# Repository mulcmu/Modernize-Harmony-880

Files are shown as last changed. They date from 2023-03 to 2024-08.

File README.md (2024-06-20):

# Modernize Harmony 880
 Modernize a Logitech Harmony 880 universal remote

# Details

The Logitech Harmony 880 is a universal infrared remote intended to control the numerous parts of a home theater system with one remote. The Harmony remotes are programmable allowing sequences of IR commands to be sent to start an activity. So "Watch Blu-ray" could be configured to turn on TV, receiver, and blu-ray player player, and set TV and receiver to correct inputs. Convenient to keep from needing numerous remotes to start an activity. Programming is performed using Logitech internet based software to update the remote via a USB connection. In 2021, Logitech announced that they would discontinue Harmony Remote [manufacturing](https://support.logi.com/hc/en-us/community/posts/1500000658341). The release indicates support would still continue software support, who knows how long that will remain.

The 880 remote build is great quality. I'm not sure exactly when I got mine but it is upwards of 15 years of service with only some cosmetic wear to the buttons. It has a rechargeable battery, that charges in a storage cradle. Over the years the universality of the remote has diminished as more devices use RF remote protocols. To keep the 880 working after getting a Roku box, an ESP8266 needed to be setup to [translate IR remote](https://github.com/mulcmu/IRtoRokuBridge) signals to HTTP POST commands.

This project is undertaking an upgrade for the 880 universal remote to, update screen to TFT with better resolution, build in wifi connectivity, and provide an open source software solution for setup and programming.

Current PCB design has all existing remote features implemented, hardware and software testing in process.

# Project Logs

https://hackaday.io/project/185926-modernize-harmony-880

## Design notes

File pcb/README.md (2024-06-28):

# Alpha3 PCB

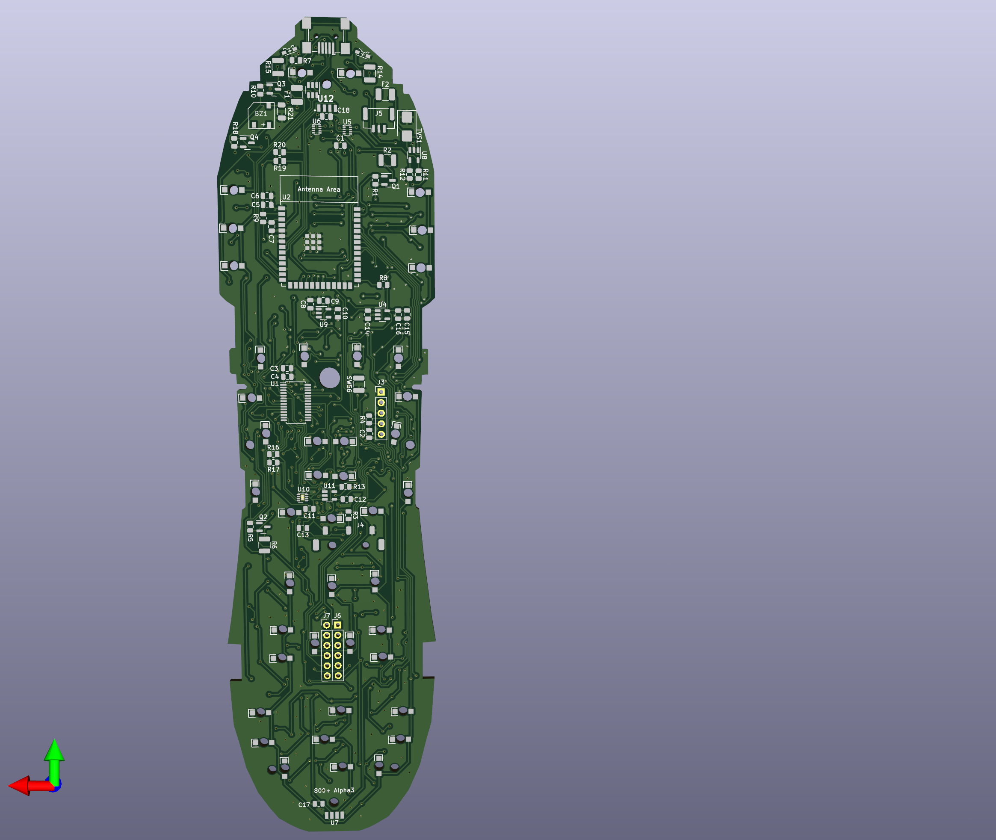
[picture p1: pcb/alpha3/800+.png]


Alpha3 PCB designed and ordered to test the peripheral operation.  Should be functionally complete if everything works.

There are some clearance issues with the bottom of remote case screw bosses interfering with parts on bottom of board.

# Alpha2 PCB

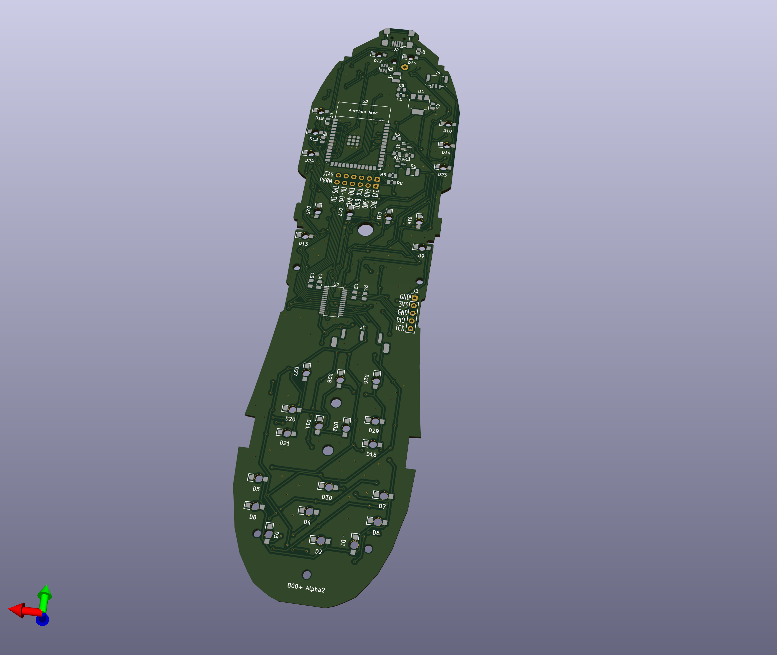
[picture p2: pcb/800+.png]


Updated the Kicad project for another alpha PCB.  Two layer PCB again but 0.8mm thick to fully test fitup with case.

* Fixed mosfet for the button led backlight
* Put an ESP32-S3 module on the board.
* USB wired up to the ESP32, 3.3V supply from the usb 5V.

# Alpha PCB

Kicad files for the alpha PCB.  Overall dimensions were okay.  The sides by the LCD might need trimmed down a smidge but there isn't much room for the button contacts.

Two layer PCB to keep cost down.  I ordered a 1.6mm thick but the stock board was 0.8mm so the case wouldn't snap shut properly.

##### Bare Screen

https://www.alibaba.com/product-detail/Lcd-Screen-Display-2-Inch-240x320_1600053711661.html

##### 4mm dome switches

https://www.aliexpress.us/item/2255799854582341

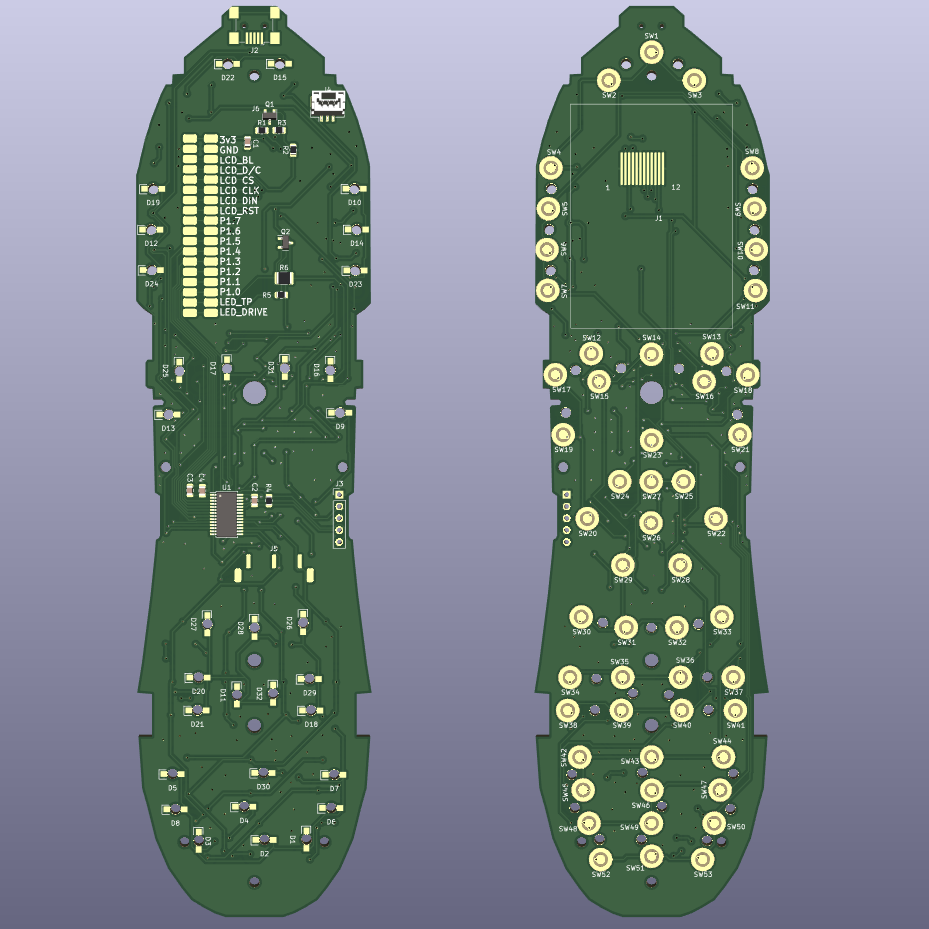
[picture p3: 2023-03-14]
pcb/alpha/back.png

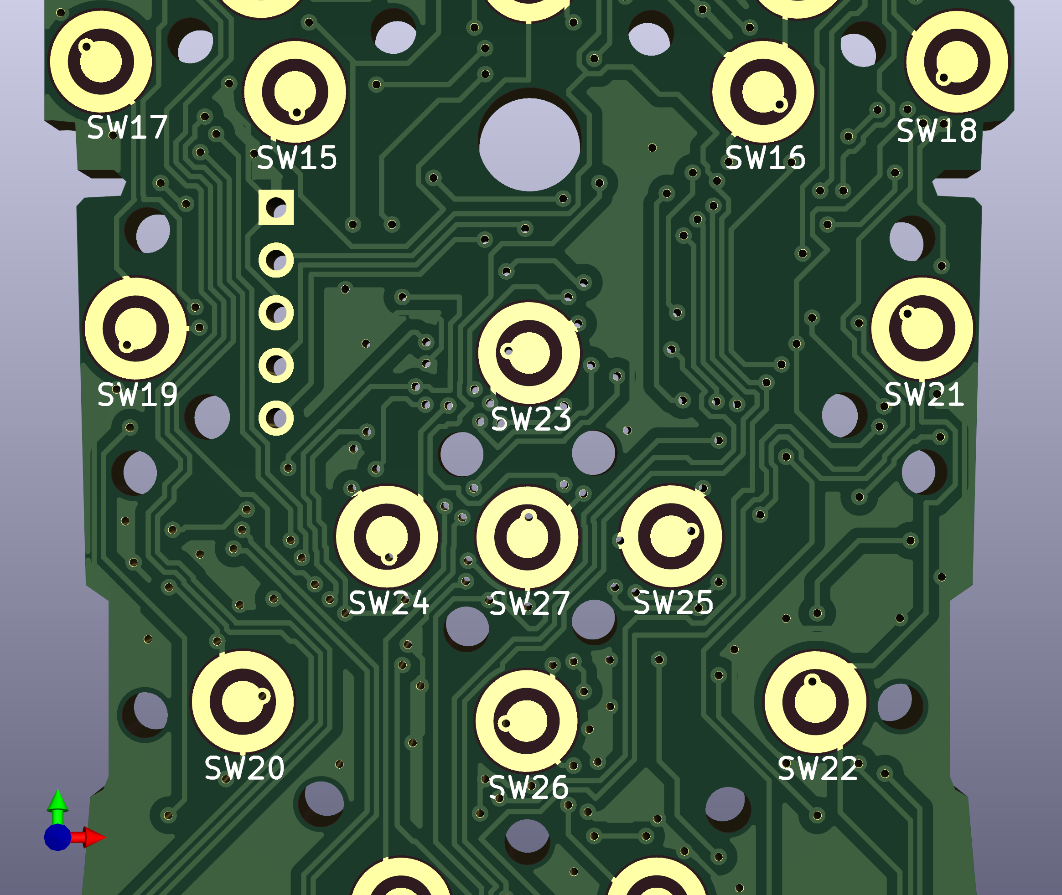
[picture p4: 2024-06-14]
pcb/alpha3/front.png

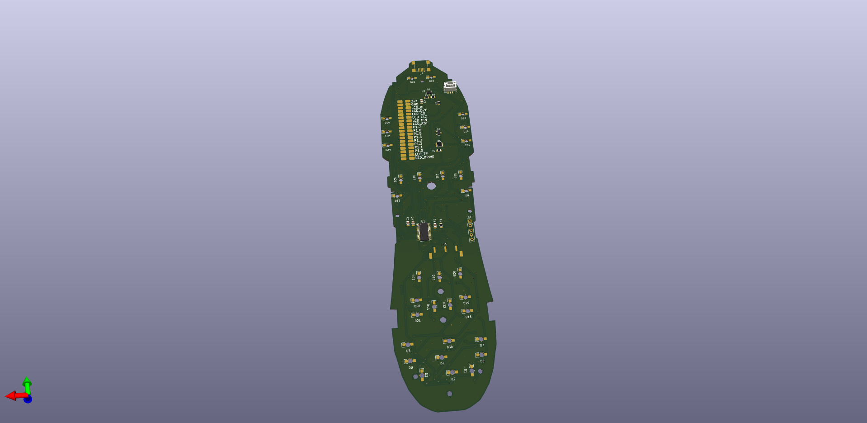
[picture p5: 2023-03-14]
pcb/alpha/iso1.png

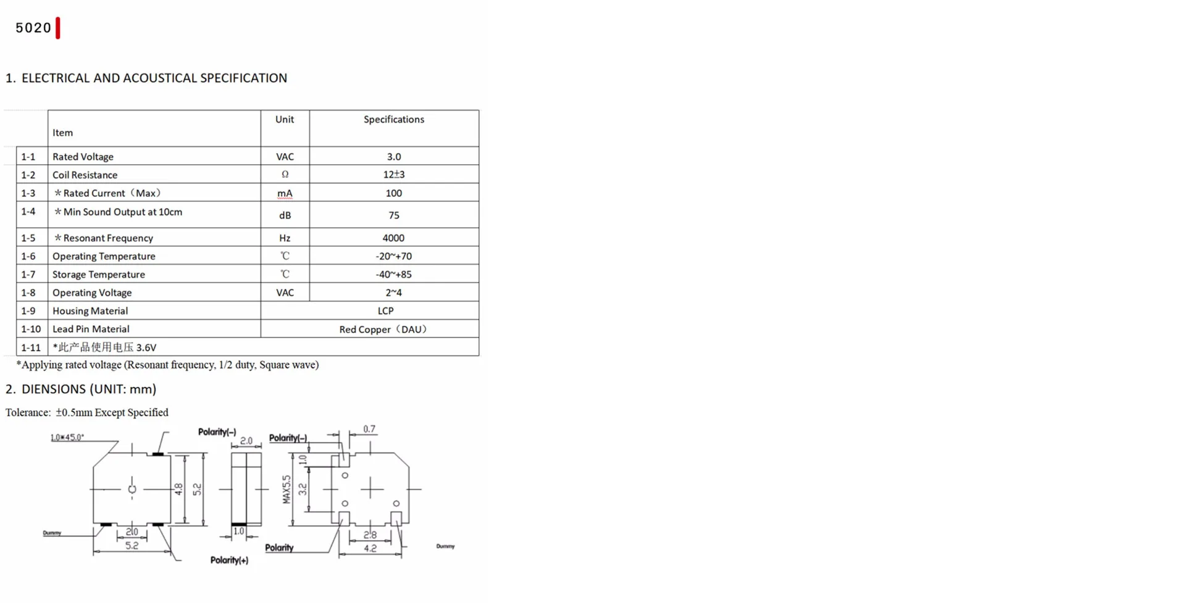
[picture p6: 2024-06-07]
pcb/buzzer.png

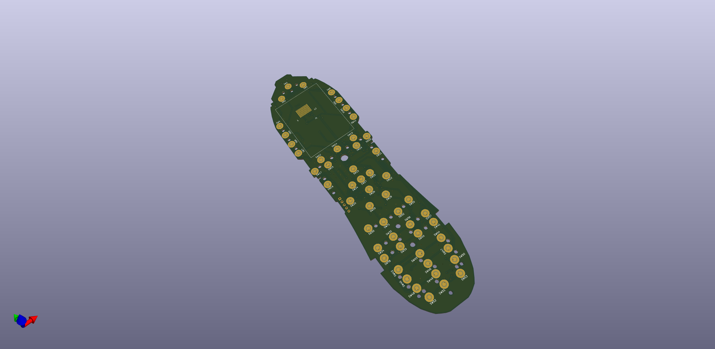
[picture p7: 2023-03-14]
pcb/alpha/iso2.png

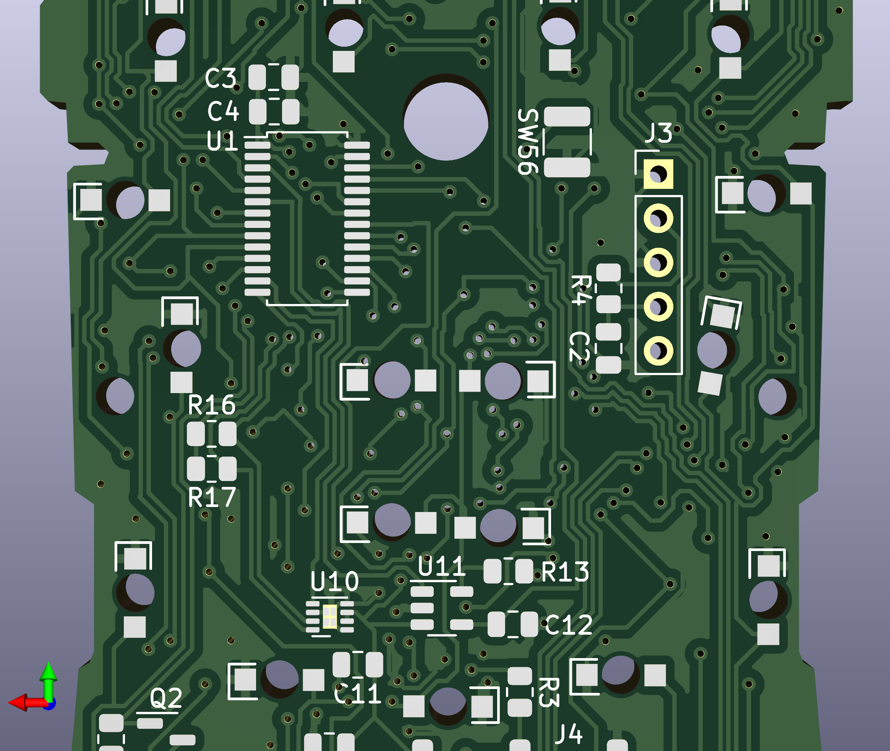
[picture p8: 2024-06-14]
pcb/alpha3/bottom.png

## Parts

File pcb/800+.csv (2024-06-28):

Source: | C:\Users\Ryan\Documents\GitHub\mulcmu\Modernize-Harmony-880\pcb\800+.kicad_sch
Date: | 6/23/2024 4:27:52 PM
Tool: | Eeschema 7.0.10
Generator: | C:\Program Files\KiCad\7.0\bin\scripting\plugins/bom_csv_grouped_by_value.py
Component Count: | 161
Collated Components:
Item | Qty | Reference(s) | Value | LibPart | Footprint | Datasheet | DNP | Imax | Iq | Manufacturer_Name | Manufacturer_Part_Number | Mouser Part Number | Mouser Price/Stock | PROD_ID | Tolerance | VMax | Voltage
1 | 1 | BZ1 | 5020 Passive | Device:Buzzer | 880+:5020passiveBuzzer | ~
2 | 2 | C1, C7 | 1u | Device:C | Capacitor_SMD:C_0805_2012Metric | ~
3 | 1 | C2 | 1.1nF | Device:C | Capacitor_SMD:C_0805_2012Metric | ~
4 | 3 | C3, C5, C6 | 10u | Device:C | Capacitor_SMD:C_0805_2012Metric | ~
5 | 1 | C4 | .1u | Device:C | Capacitor_SMD:C_0805_2012Metric | ~
6 | 2 | C8, C14 | 2.2uF | SparkFun-Capacitor:2.2uF_0402_10V_10% | SparkFun-Capacitor:C_0402_1005Metric | https://cdn.sparkfun.com/assets/8/a/4/a/5/Kemet_Capacitor_Datasheet.pdf |  |  |  |  |  |  |  | CAP-14232 | 10% |  | 10V
7 | 3 | C9, C11, C15 | 0.1uF | SparkFun-Capacitor:0.1uF_0402_6.3V_10% | SparkFun-Capacitor:C_0402_1005Metric | https://cdn.sparkfun.com/assets/8/a/4/a/5/Kemet_Capacitor_Datasheet.pdf |  |  |  |  |  |  |  | CAP-14993 | 10% |  | 6.3V
8 | 2 | C10, C16 | 1.0uF | SparkFun-Capacitor:1.0uF_0402_16V_10% | SparkFun-Capacitor:C_0402_1005Metric | https://cdn.sparkfun.com/assets/8/a/4/a/5/Kemet_Capacitor_Datasheet.pdf |  |  |  |  |  |  |  | CAP-14969 | 10% |  | 16V
9 | 1 | C12 | 4.7uF | SparkFun-Capacitor:4.7uF_0603_35V_20% | SparkFun-Capacitor:C_0603_1608Metric | https://cdn.sparkfun.com/assets/8/a/4/a/5/Kemet_Capacitor_Datasheet.pdf |  |  |  |  |  |  |  | CAP-14106 | 20% |  | 35V
10 | 1 | C13 | 4.7uF | SparkFun-Capacitor:4.7uF_0402_6.3V_10% | SparkFun-Capacitor:C_0402_1005Metric | https://cdn.sparkfun.com/assets/8/a/4/a/5/Kemet_Capacitor_Datasheet.pdf |  |  |  |  |  |  |  | CAP-14240 | 20% |  | 6.3V
11 | 32 | D1, D2, D3, D4, D5, D6, D7, D8, D9, D10, D11, D12, D13, D14, D15, D16, D17, D18, D19, D20, D21, D22, D23, D24, D25, D26, D27, D28, D29, D30, D31, D32 | LED | Device:LED | 880+:C265_reverse_mount_led_DRC | ~
12 | 2 | D33, D34 | LED | Device:LED | 880+:IR_led | ~
13 | 1 | D35 | P6SMB12CA | Device:D_TVS | Diode_SMD:D_SMB | ~
14 | 2 | F1, F2 | Polyfuse | Device:Polyfuse | Resistor_SMD:R_1210_3225Metric_Pad1.30x2.65mm_HandSolder | https://www.mouser.com/ProductDetail/Bourns/MF-MSMF030-2?qs=4Enggx7jqVwuh3vnyeU3lA%3D%3D
15 | 1 | H1 | Screw Recess | Mechanical:MountingHole | MountingHole:MountingHole_5mm | ~
16 | 2 | H4, H5 | Battery Alignment | Mechanical:MountingHole | MountingHole:MountingHole_2.1mm | ~
17 | 4 | H6, H7, H8, H9 | Case Screw | Mechanical:MountingHole | MountingHole:MountingHole_2.2mm_M2 | ~
18 | 1 | J1 | 2inch LCD | Connector_Generic:Conn_01x12 | 880+:2inch_LCD | ~
19 | 1 | J2 | USB_B_Micro | Connector:USB_B_Micro | Connector_USB:USB_Mini-B_Wuerth_65100516121_Horizontal | ~
20 | 1 | J3 | MSP_SBW | Connector_Generic:Conn_01x05 | Connector_PinHeader_2.54mm:PinHeader_1x05_P2.54mm_Vertical | ~
21 | 1 | J4 | Battery | Connector_Generic:Conn_01x03 | 880+:Battery_reuse | ~
22 | 1 | J5 | Cradle | Connector_Generic:Conn_01x03 | Connector_JST:JST_GH_BM03B-GHS-TBT_1x03-1MP_P1.25mm_Vertical | ~
23 | 1 | J6 | ESP_JTAG | Connector:Conn_01x06_Socket | Connector_PinHeader_2.54mm:PinHeader_1x06_P2.54mm_Vertical | ~
24 | 1 | J7 | ESP_PROG | Connector:Conn_01x06_Socket | Connector_PinHeader_2.54mm:PinHeader_1x06_P2.54mm_Vertical | ~
25 | 4 | Q1, Q2, Q3, Q4 | AO3401A | Transistor_FET:AO3401A | Package_TO_SOT_SMD:SOT-23 | http://www.aosmd.com/pdfs/datasheet/AO3401A.pdf
26 | 6 | R1, R5, R8, R9, R10, R18 | 10k | Device:R | Resistor_SMD:R_0805_2012Metric | ~
27 | 2 | R2, R6 | 10 | Device:R | Resistor_SMD:R_1210_3225Metric | ~
28 | 1 | R3 | R | Device:R | Resistor_SMD:R_0805_2012Metric | ~
29 | 1 | R4 | 47k | Device:R | Resistor_SMD:R_0805_2012Metric | ~
30 | 1 | R7 | 1M | Device:R | Resistor_SMD:R_0805_2012Metric | ~
31 | 2 | R11, R12 | R | Device:R |  | ~
32 | 1 | R13 | 2k | Device:R | Resistor_SMD:R_0805_2012Metric | ~
33 | 2 | R14, R15 | 22 | Device:R | Resistor_SMD:R_1210_3225Metric | ~
34 | 4 | R16, R17, R19, R20 | 4.7k | Device:R | Resistor_SMD:R_0805_2012Metric | ~
35 | 1 | R21 | 0 | Device:R | Resistor_SMD:R_1206_3216Metric | ~
36 | 1 | SW1 | Off | Switch:SW_Push | 880+:4mm Dome | ~
37 | 1 | SW2 | Activities | Switch:SW_Push | 880+:4mm Dome | ~
38 | 1 | SW3 | Help | Switch:SW_Push | 880+:4mm Dome | ~
39 | 1 | SW4 | L_LCD1 | Switch:SW_Push | 880+:4mm Dome | ~
40 | 1 | SW5 | L_LCD2 | Switch:SW_Push | 880+:4mm Dome | ~
41 | 1 | SW6 | L_LCD3 | Switch:SW_Push | 880+:4mm Dome | ~
42 | 1 | SW7 | L_LCD4 | Switch:SW_Push | 880+:4mm Dome | ~
43 | 1 | SW8 | R_LCD1 | Switch:SW_Push | 880+:4mm Dome | ~
44 | 1 | SW9 | R_LCD2 | Switch:SW_Push | 880+:4mm Dome | ~
45 | 1 | SW10 | R_LCD3 | Switch:SW_Push | 880+:4mm Dome | ~
46 | 1 | SW11 | R_LCD4 | Switch:SW_Push | 880+:4mm Dome | ~
47 | 1 | SW12 | LCD_LEFT | Switch:SW_Push | 880+:4mm Dome | ~
48 | 1 | SW13 | LCD_RIGHT | Switch:SW_Push | 880+:4mm Dome | ~
49 | 1 | SW14 | Glow | Switch:SW_Push | 880+:4mm Dome | ~
50 | 1 | SW15 | Device | Switch:SW_Push | 880+:4mm Dome | ~
51 | 1 | SW16 | Media | Switch:SW_Push | 880+:4mm Dome | ~
52 | 1 | SW17 | Mute | Switch:SW_Push | 880+:4mm Dome | ~
53 | 1 | SW18 | Prev | Switch:SW_Push | 880+:4mm Dome | ~
54 | 1 | SW19 | Vol+ | Switch:SW_Push | 880+:4mm Dome | ~
55 | 1 | SW20 | Vol- | Switch:SW_Push | 880+:4mm Dome | ~
56 | 1 | SW21 | Ch+ | Switch:SW_Push | 880+:4mm Dome | ~
57 | 1 | SW22 | Ch- | Switch:SW_Push | 880+:4mm Dome | ~
58 | 1 | SW23 | Dpad_Up | Switch:SW_Push | 880+:4mm Dome | ~
59 | 1 | SW24 | Dpad_Left | Switch:SW_Push | 880+:4mm Dome | ~
60 | 1 | SW25 | Dpad_Right | Switch:SW_Push | 880+:4mm Dome | ~
61 | 1 | SW26 | Dpad_Down | Switch:SW_Push | 880+:4mm Dome | ~
62 | 1 | SW27 | Dpad_OK | Switch:SW_Push | 880+:4mm Dome | ~
63 | 1 | SW28 | PgUp/Grn | Switch:SW_Push | 880+:4mm Dome | ~
64 | 1 | SW29 | PgDown/Yel | Switch:SW_Push | 880+:4mm Dome | ~
65 | 1 | SW30 | Menu | Switch:SW_Push | 880+:4mm Dome | ~
66 | 1 | SW31 | Exit | Switch:SW_Push | 880+:4mm Dome | ~
67 | 1 | SW32 | Guide | Switch:SW_Push | 880+:4mm Dome | ~
68 | 1 | SW33 | Info | Switch:SW_Push | 880+:4mm Dome | ~
69 | 1 | SW34 | Stop | Switch:SW_Push | 880+:4mm Dome | ~
70 | 1 | SW35 | Replay | Switch:SW_Push | 880+:4mm Dome | ~
71 | 1 | SW36 | Skip | Switch:SW_Push | 880+:4mm Dome | ~
72 | 1 | SW37 | Play | Switch:SW_Push | 880+:4mm Dome | ~
73 | 1 | SW38 | Rec | Switch:SW_Push | 880+:4mm Dome | ~
74 | 1 | SW39 | Rew | Switch:SW_Push | 880+:4mm Dome | ~
75 | 1 | SW40 | Fwd | Switch:SW_Push | 880+:4mm Dome | ~
76 | 1 | SW41 | Pause | Switch:SW_Push | 880+:4mm Dome | ~
77 | 1 | SW42 | KP_1 | Switch:SW_Push | 880+:4mm Dome | ~
78 | 1 | SW43 | KP_2 | Switch:SW_Push | 880+:4mm Dome | ~
79 | 1 | SW44 | KP_3 | Switch:SW_Push | 880+:4mm Dome | ~
80 | 1 | SW45 | KP_4 | Switch:SW_Push | 880+:4mm Dome | ~
81 | 1 | SW46 | KP_5 | Switch:SW_Push | 880+:4mm Dome | ~
82 | 1 | SW47 | KP_6 | Switch:SW_Push | 880+:4mm Dome | ~
83 | 1 | SW48 | KP_7 | Switch:SW_Push | 880+:4mm Dome | ~
84 | 1 | SW49 | KP_8 | Switch:SW_Push | 880+:4mm Dome | ~
85 | 1 | SW50 | KP_9 | Switch:SW_Push | 880+:4mm Dome | ~
86 | 1 | SW51 | KP_0 | Switch:SW_Push | 880+:4mm Dome | ~
87 | 1 | SW52 | KP_Clear | Switch:SW_Push | 880+:4mm Dome | ~
88 | 1 | SW53 | KP_Enter | Switch:SW_Push | 880+:4mm Dome | ~
89 | 1 | SW54 | Red | Switch:SW_Push | 880+:4mm Dome | ~
90 | 1 | SW55 | Blue | Switch:SW_Push | 880+:4mm Dome | ~
91 | 1 | SW56 | SW_RollingBall | 880+:SW_RollingBall | Resistor_SMD:R_1210_3225Metric | ~
92 | 1 | U1 | MSP430G2553IPW28 | MCU_Texas_MSP430:MSP430G2553IPW28 | Package_SO:TSSOP-28_4.4x9.7mm_P0.65mm | http://www.ti.com/lit/ds/symlink/msp430g2553.pdf
93 | 1 | U2 | ESP32-S3-WROOM-1U | PCM_Espressif:ESP32-S3-WROOM-1 | PCM_Espressif:ESP32-S3-WROOM-1 | https://www.espressif.com/sites/default/files/documentation/esp32-s3-wroom-1_wroom-1u_datasheet_en.pdf
94 | 1 | U3 | USBLC6-2 | Random_SRAM_Parts:USBLC6_Fixed | Package_TO_SOT_SMD:SOT-23-6
95 | 2 | U4, U9 | RT9080-3.3 | SparkFun-Regulator:RT9080-3.3 | SparkFun-Semiconductor-Standard:SOT23-5 | https://www.richtek.com/SaveDownload.aspx?specid=RT9080 |  | 600mA | 4µA |  |  |  |  | VREG-19034 |  | 6V
96 | 2 | U5, U6 | LM66200DRLR | 880+:LM66200DRLR | SOT-5X3_DRL_TEX | LM66200DRLR
97 | 1 | U7 | TSOP75340TT | 880+:TSOP75340TT | 880+:IR_input
98 | 1 | U8 | SPX3819M5-L | Regulator_Linear:SPX3819M5-L | Package_TO_SOT_SMD:SOT-23-5 | https://www.exar.com/content/document.ashx?id=22106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
99 | 1 | U10 | MAX17048 | SparkFun-IC-Power:MAX17048 | SparkFun-Semiconductor-Standard:DFN-8 | https://www.analog.com/media/en/technical-documentation/data-sheets/MAX17048-MAX17049.pdf |  |  |  |  |  |  |  | IC-12551
100 | 1 | U11 | MCP73831 | SparkFun-IC-Power:MCP73831 | SparkFun-Semiconductor-Standard:SOT23-5 | http://ww1.microchip.com/downloads/en/DeviceDoc/20001984g.pdf |  |  |  |  |  |  |  | IC-09995
101 | 1 | U12 | VEML7700-TR | 880+:VEML7700-TT | 880+:VEML7700 | https://www.arrow.com/en/products/veml7700-tt/vishay |  |  |  | Vishay | VEML7700-TT | 78-VEML7700-TT | https://www.mouser.co.uk/ProductDetail/Vishay-Semiconductors/VEML7700-TT?qs=BcfjnG7NVaXdL6DJFdWbdw%3D%3D

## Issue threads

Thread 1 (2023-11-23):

Status on PCB

mbake2, 2023-11-23:
What's the status on the PCB boards of the remote? Last time I checked, you had the alpha PCBs built.

mulcmu, 2023-11-24:
No recent progress.  I ordered a few ESP32-S3 modules intended for use with this project but haven't worked on it.

mbake2, 2023-11-24:
Ok. Where would I get the PCBs when they’re ready?

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

mulcmu, 2023-11-24:
I ordered the originals from jlcpcb.com as bare boards.

mbake2, 2023-11-24:
Can you remind me when the PCBs are done and mail one to me? Thanks

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

mulcmu, 2023-11-24:
Sure.  I'll reach out when they are ready.

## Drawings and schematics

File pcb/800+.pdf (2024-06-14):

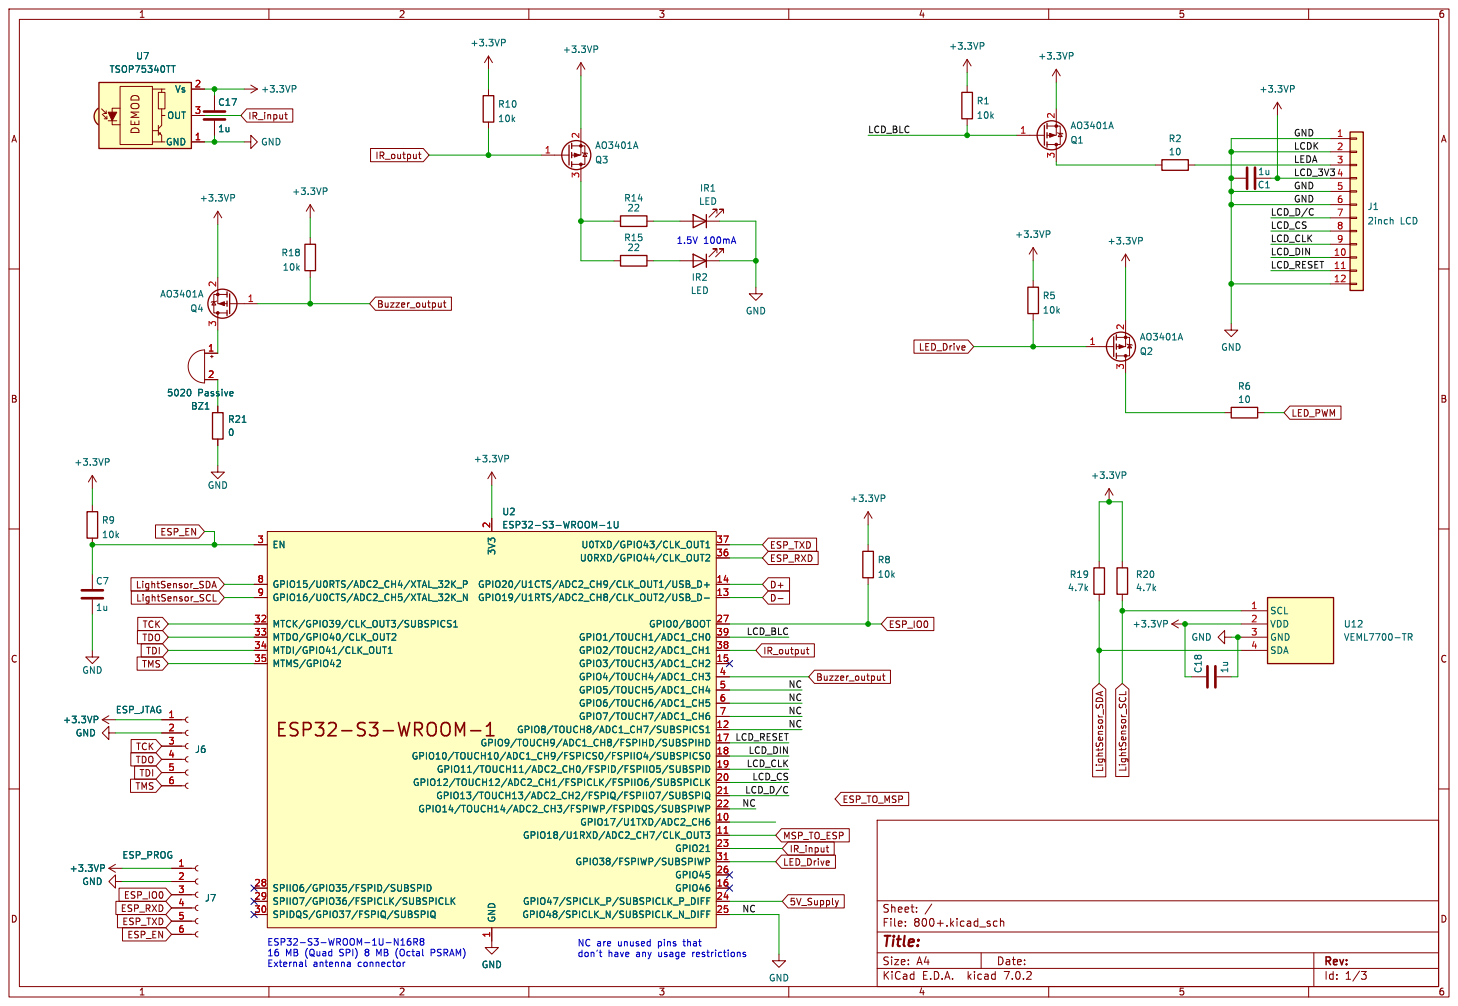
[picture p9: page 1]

2 GPIO12/TOUCH12/ADC2_CH1/FSPICLK/FSPIIO6/SUBSPICLK 20 GPIO13/TOUCH13/ADC2_CH2/FSPIQ/FSPIIO7/SUBSPIQ 21 GPIO14/TOUCH14/ADC2_CH3/FSPIWP/FSPIDQS/SUBSPIWP 22 GPIO21 23 GPIO47/SPICLK_P/SUBSPICLK_P_DIFF 24 GPIO48/SPICLK_N/SUBSPICLK_N_DIFF 25 GPIO45 26 GPIO0/BOOT 27 SPIIO6/GPIO35/FSPID/SUBSPID 28 SPIIO7/GPIO36/FSPICLK/SUBSPICLK 29 EN 3 SPIDQS/GPIO37/FSPIQ/SUBSPIQ 30 GPIO38/FSPIWP/SUBSPIWP 31 MTCK/GPIO39/CLK_OUT3/SUBSPICS1 32 MTDO/GPIO40/CLK_OUT2 33 MTDI/GPIO41/CLK_OUT1 34 MTMS/GPIO42 35 U0RXD/GPIO44/CLK_OUT2 36 U0TXD/GPIO43/CLK_OUT1 37 GPIO2/TOUCH2/ADC1_CH1 38 GPIO1/TOUCH1/ADC1_CH0 39 GPIO4/TOUCH4/ADC1_CH3 4 GPIO5/TOUCH5/ADC1_CH4 5 GPIO6/TOUCH6/ADC1_CH5 6 GPIO7/TOUCH7/ADC1_CH6 7 GPIO15/U0RTS/ADC2_CH4/XTAL_32K_P 8 GPIO16/U0CTS/ADC2_CH5/XTAL_32K_N 9 U2ESP32-S3-WROOM-1U

NC are unused pins that don't have any usage restrictions U2ESP32-S3-WROOM-1U GND

2 GPIO12/TOUCH12/ADC2_CH1/FSPICLK/FSPIIO6/SUBSPICLK 20 GPIO13/TOUCH13/ADC2_CH2/FSPIQ/FSPIIO7/SUBSPIQ 21 GPIO14/TOUCH14/ADC2_CH3/FSPIWP/FSPIDQS/SUBSPIWP 22 GPIO21 23 GPIO47/SPICLK_P/SUBSPICLK_P_DIFF 24 GPIO48/SPICLK_N/SUBSPICLK_N_DIFF 25 GPIO45 26 GPIO0/BOOT 27 SPIIO6/GPIO35/FSPID/SUBSPID 28 SPIIO7/GPIO36/FSPICLK/SUBSPICLK 29 EN 3 SPIDQS/GPIO37/FSPIQ/SUBSPIQ 30 GPIO38/FSPIWP/SUBSPIWP 31 MTCK/GPIO39/CLK_OUT3/SUBSPICS1 32 MTDO/GPIO40/CLK_OUT2 33 MTDI/GPIO41/CLK_OUT1 34 MTMS/GPIO42 35 U0RXD/GPIO44/CLK_OUT2 36 U0TXD/GPIO43/CLK_OUT1 37 GPIO2/TOUCH2/ADC1_CH1 38 GPIO1/TOUCH1/ADC1_CH0 39 GPIO4/TOUCH4/ADC1_CH3 4 GPIO5/TOUCH5/ADC1_CH4 5 GPIO6/TOUCH6/ADC1_CH5 6 GPIO7/TOUCH7/ADC1_CH6 7 GPIO15/U0RTS/ADC2_CH4/XTAL_32K_P 8 GPIO16/U0CTS/ADC2_CH5/XTAL_32K_N 9 GND

1 GPIO17/U1TXD/ADC2_CH6 10 GPIO18/U1RXD/ADC2_CH7/CLK_OUT3 11 GPIO8/TOUCH8/ADC1_CH7/SUBSPICS1 12 GPIO19/U1RTS/ADC2_CH8/CLK_OUT2/USB_D- 13 GPIO20/U1CTS/ADC2_CH9/CLK_OUT1/USB_D+ 14 GPIO3/TOUCH3/ADC1_CH2 15 GPIO46 16 GPIO9/TOUCH9/ADC1_CH8/FSPIHD/SUBSPIHD 17 GPIO10/TOUCH10/ADC1_CH9/FSPICS0/FSPIIO4/SUBSPICS0 18 GPIO11/TOUCH11/ADC2_CH0/FSPID/FSPIIO5/SUBSPID 19 3V3

Id: 1/3 Title: File: 800+.kicad_sch Sheet: /

16 MB (Quad SPI) 8 MB (Octal PSRAM) External antenna connector TODO

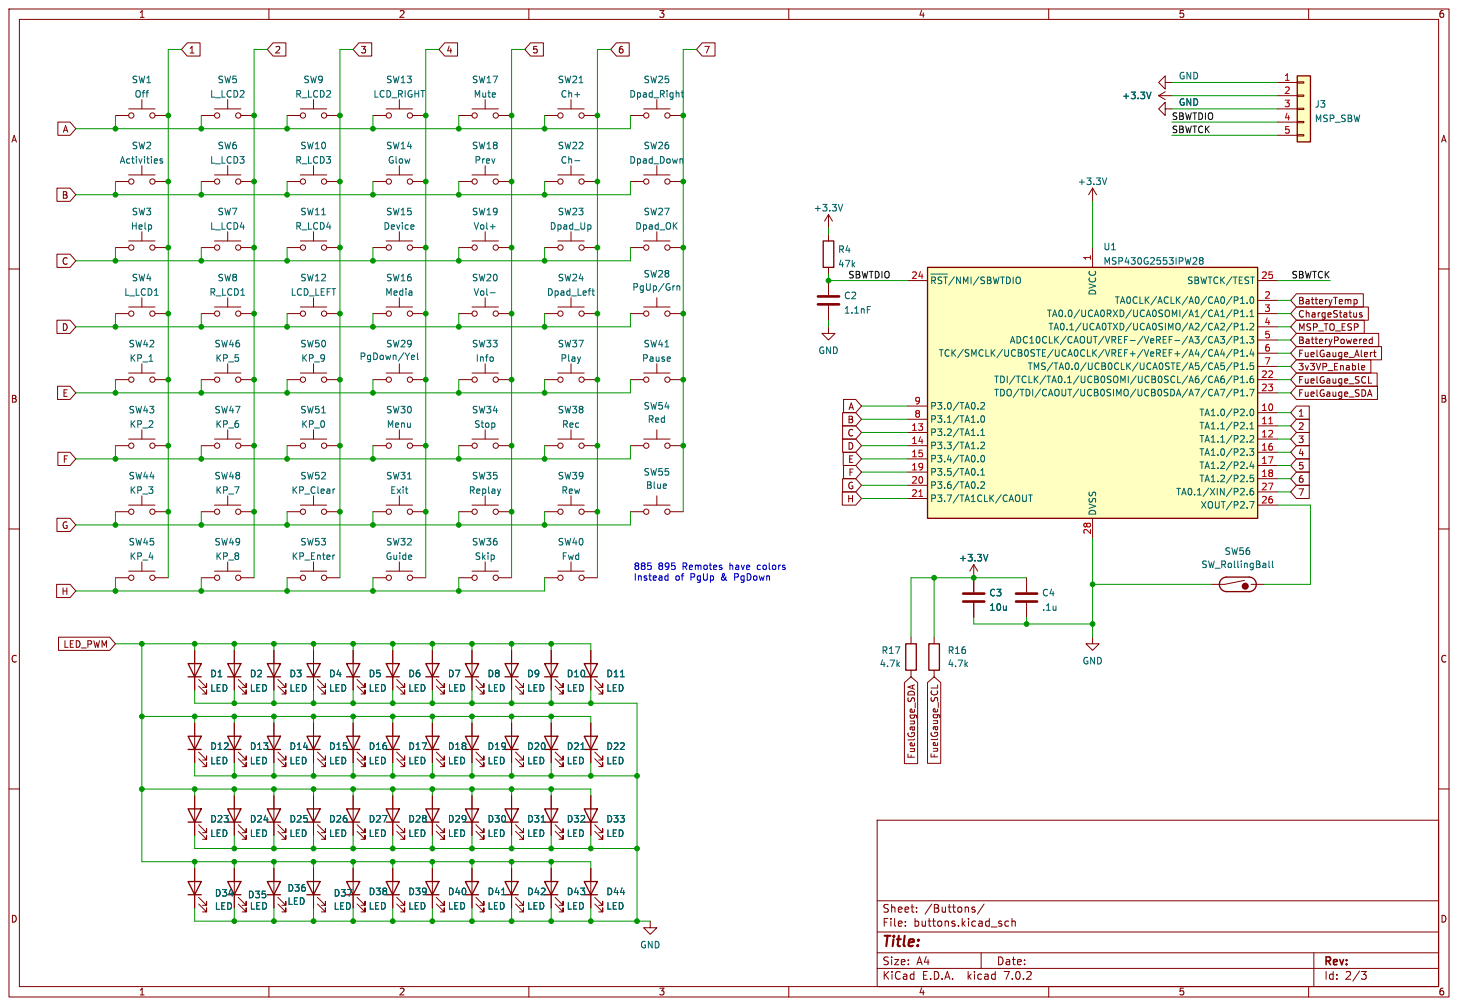
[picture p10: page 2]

Instead of PgUp & PgDown D43

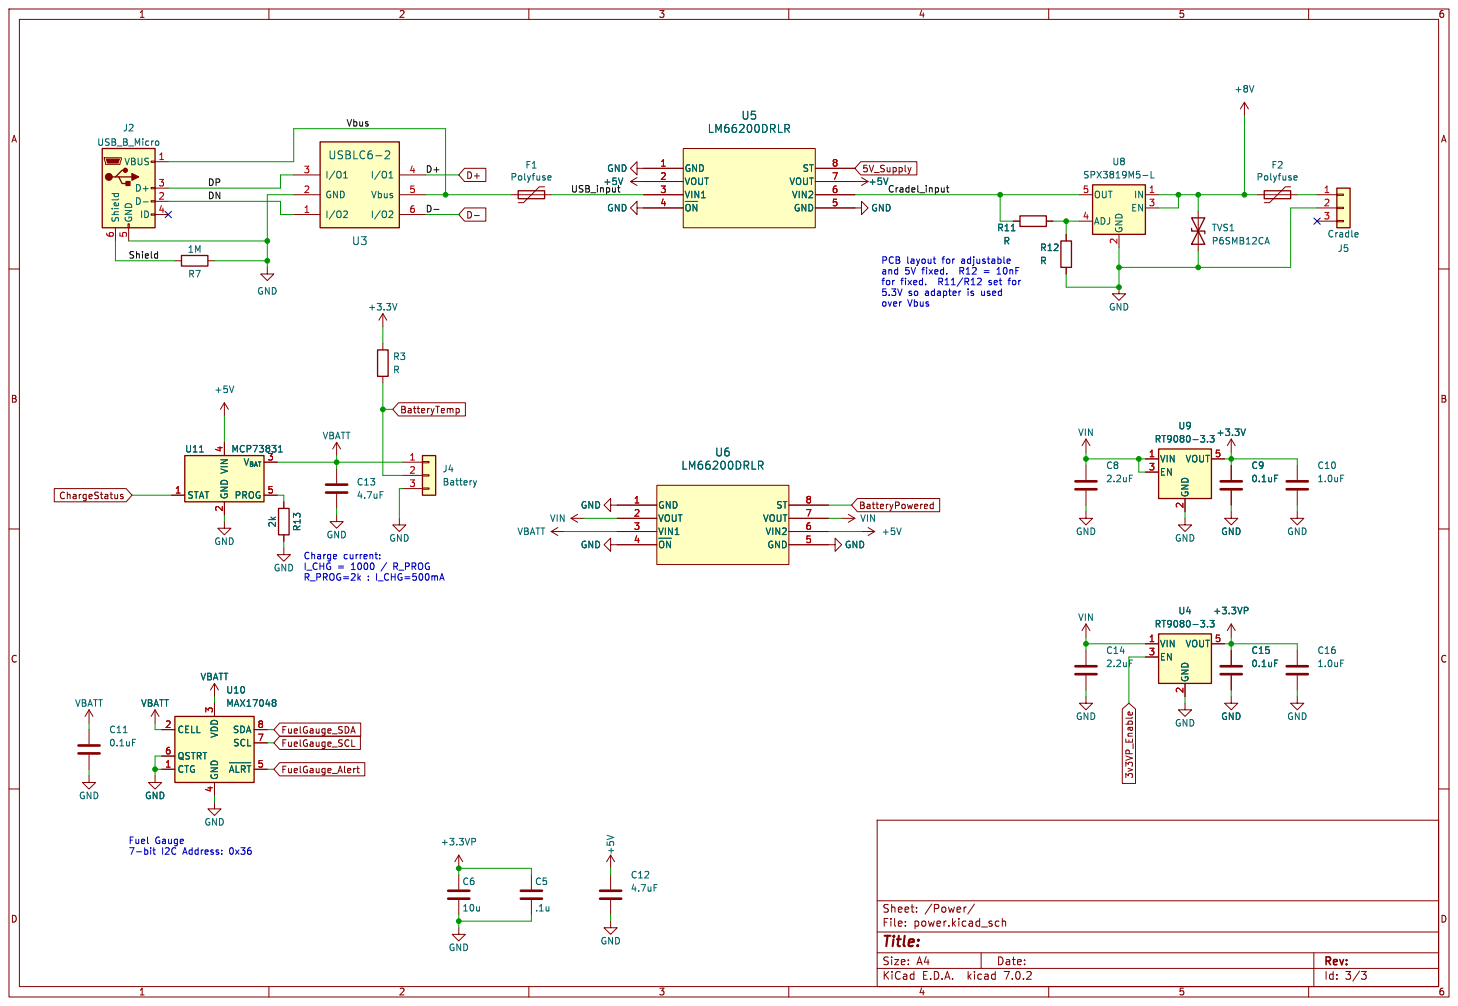
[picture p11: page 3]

4 PROG 5 U11 MCP73831 GND 1 VOUT 2 VIN1 3 GND 5 VIN2 6 VOUT 7 ST 8 ~{ON} 4 U5
D+D- FuelGauge_SDA

2 EN 3 ADJ 4 OUT 5 U8 SPX3819M5-L GND

2 EN 3 VOUT 5 U4 RT9080-3.3 VBATT GND

2 EN 3 VOUT 5 U11 MCP73831 STAT 1 GND

4 ~{ALRT}5 QSTRT 6 SCL 7 SDA 8 VBATT GND R13 2k

4 ~{ALRT}5 QSTRT 6 SCL 7 SDA 8 U10 VBATT MAX17048 GND GND GND

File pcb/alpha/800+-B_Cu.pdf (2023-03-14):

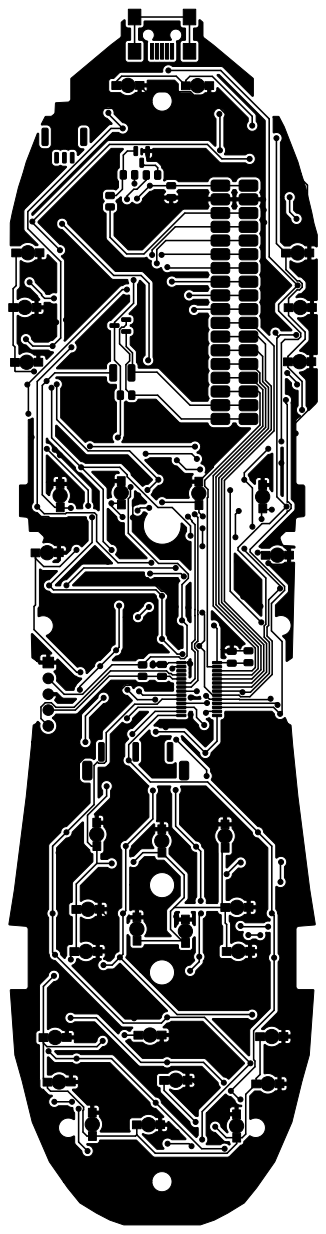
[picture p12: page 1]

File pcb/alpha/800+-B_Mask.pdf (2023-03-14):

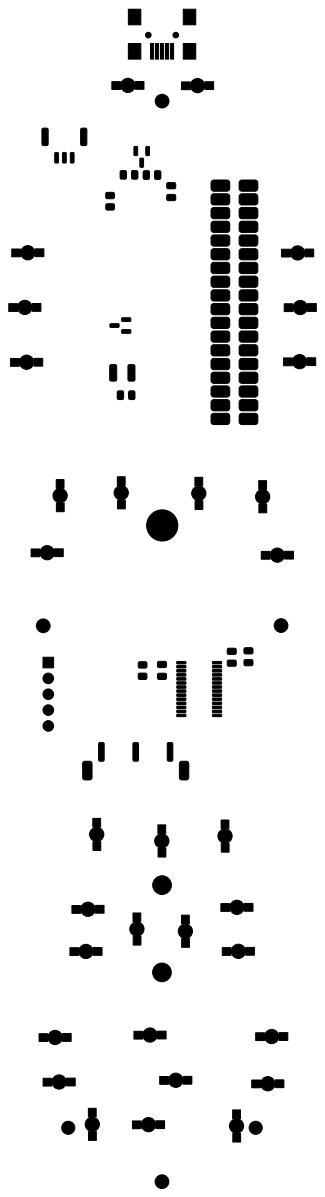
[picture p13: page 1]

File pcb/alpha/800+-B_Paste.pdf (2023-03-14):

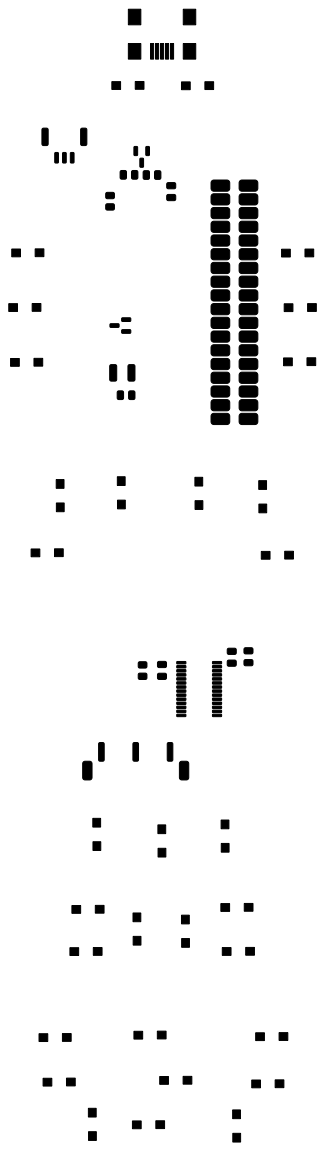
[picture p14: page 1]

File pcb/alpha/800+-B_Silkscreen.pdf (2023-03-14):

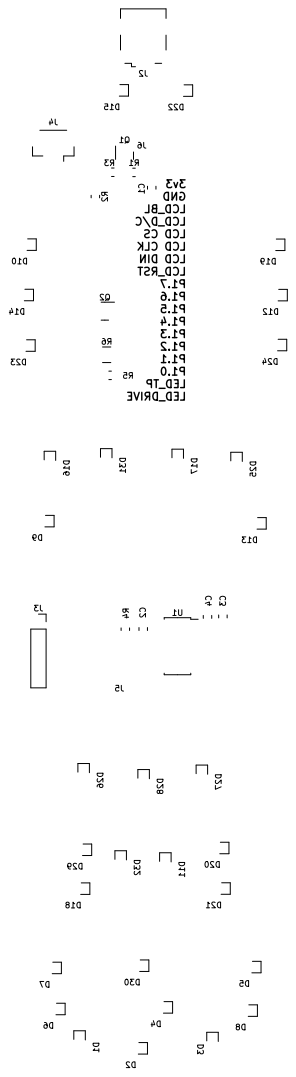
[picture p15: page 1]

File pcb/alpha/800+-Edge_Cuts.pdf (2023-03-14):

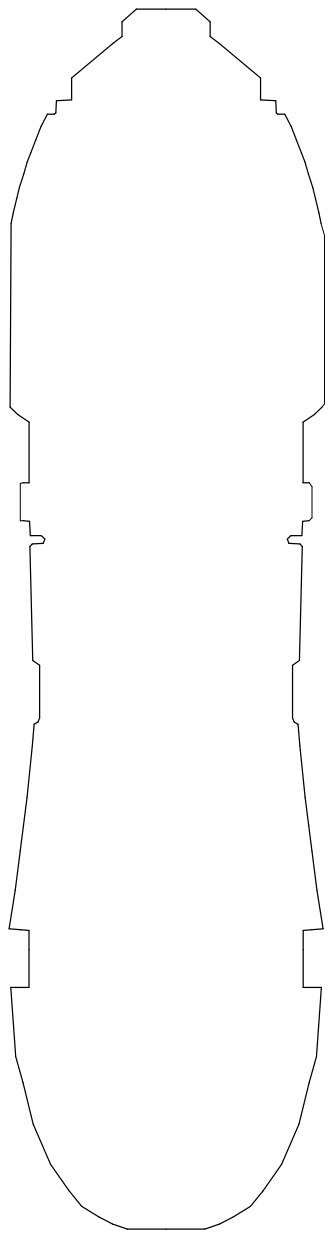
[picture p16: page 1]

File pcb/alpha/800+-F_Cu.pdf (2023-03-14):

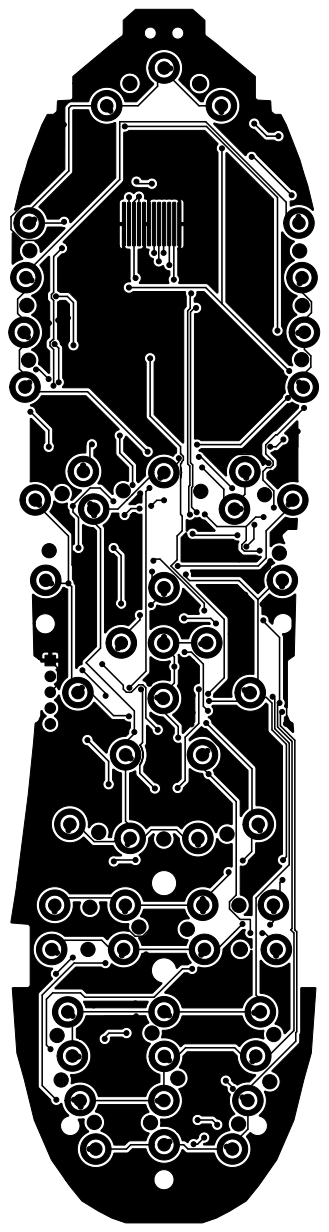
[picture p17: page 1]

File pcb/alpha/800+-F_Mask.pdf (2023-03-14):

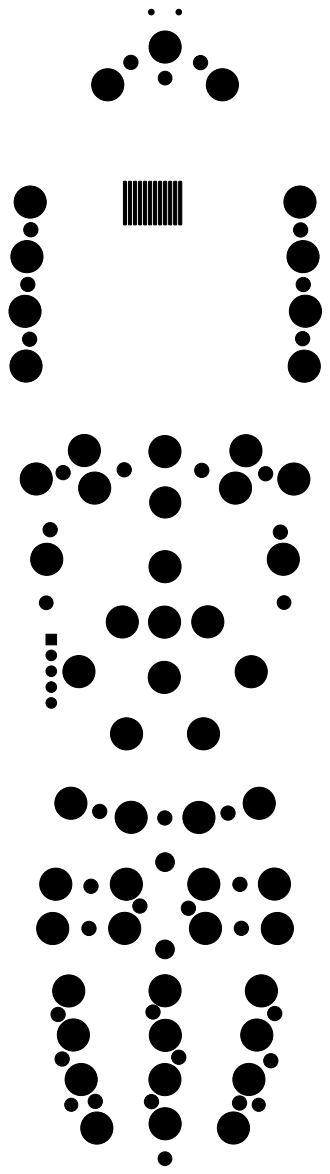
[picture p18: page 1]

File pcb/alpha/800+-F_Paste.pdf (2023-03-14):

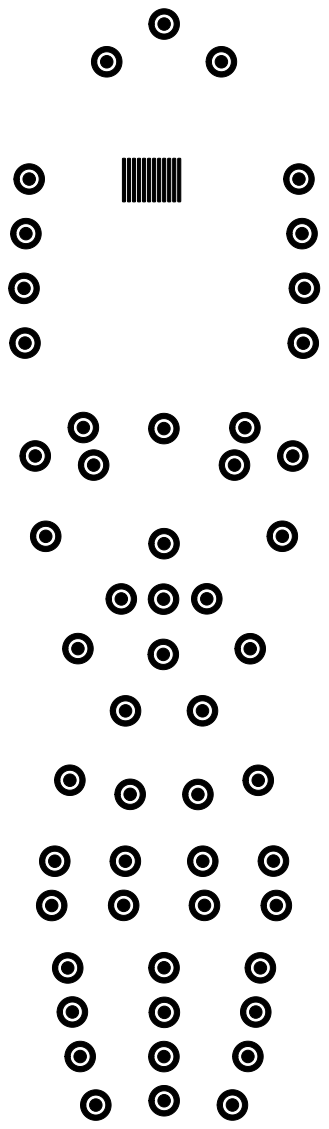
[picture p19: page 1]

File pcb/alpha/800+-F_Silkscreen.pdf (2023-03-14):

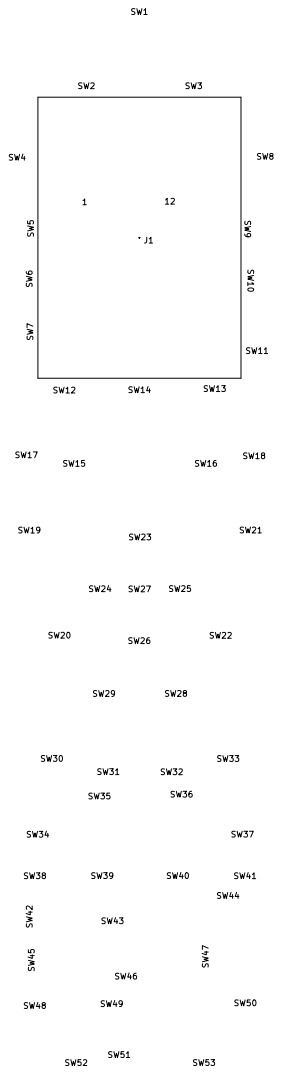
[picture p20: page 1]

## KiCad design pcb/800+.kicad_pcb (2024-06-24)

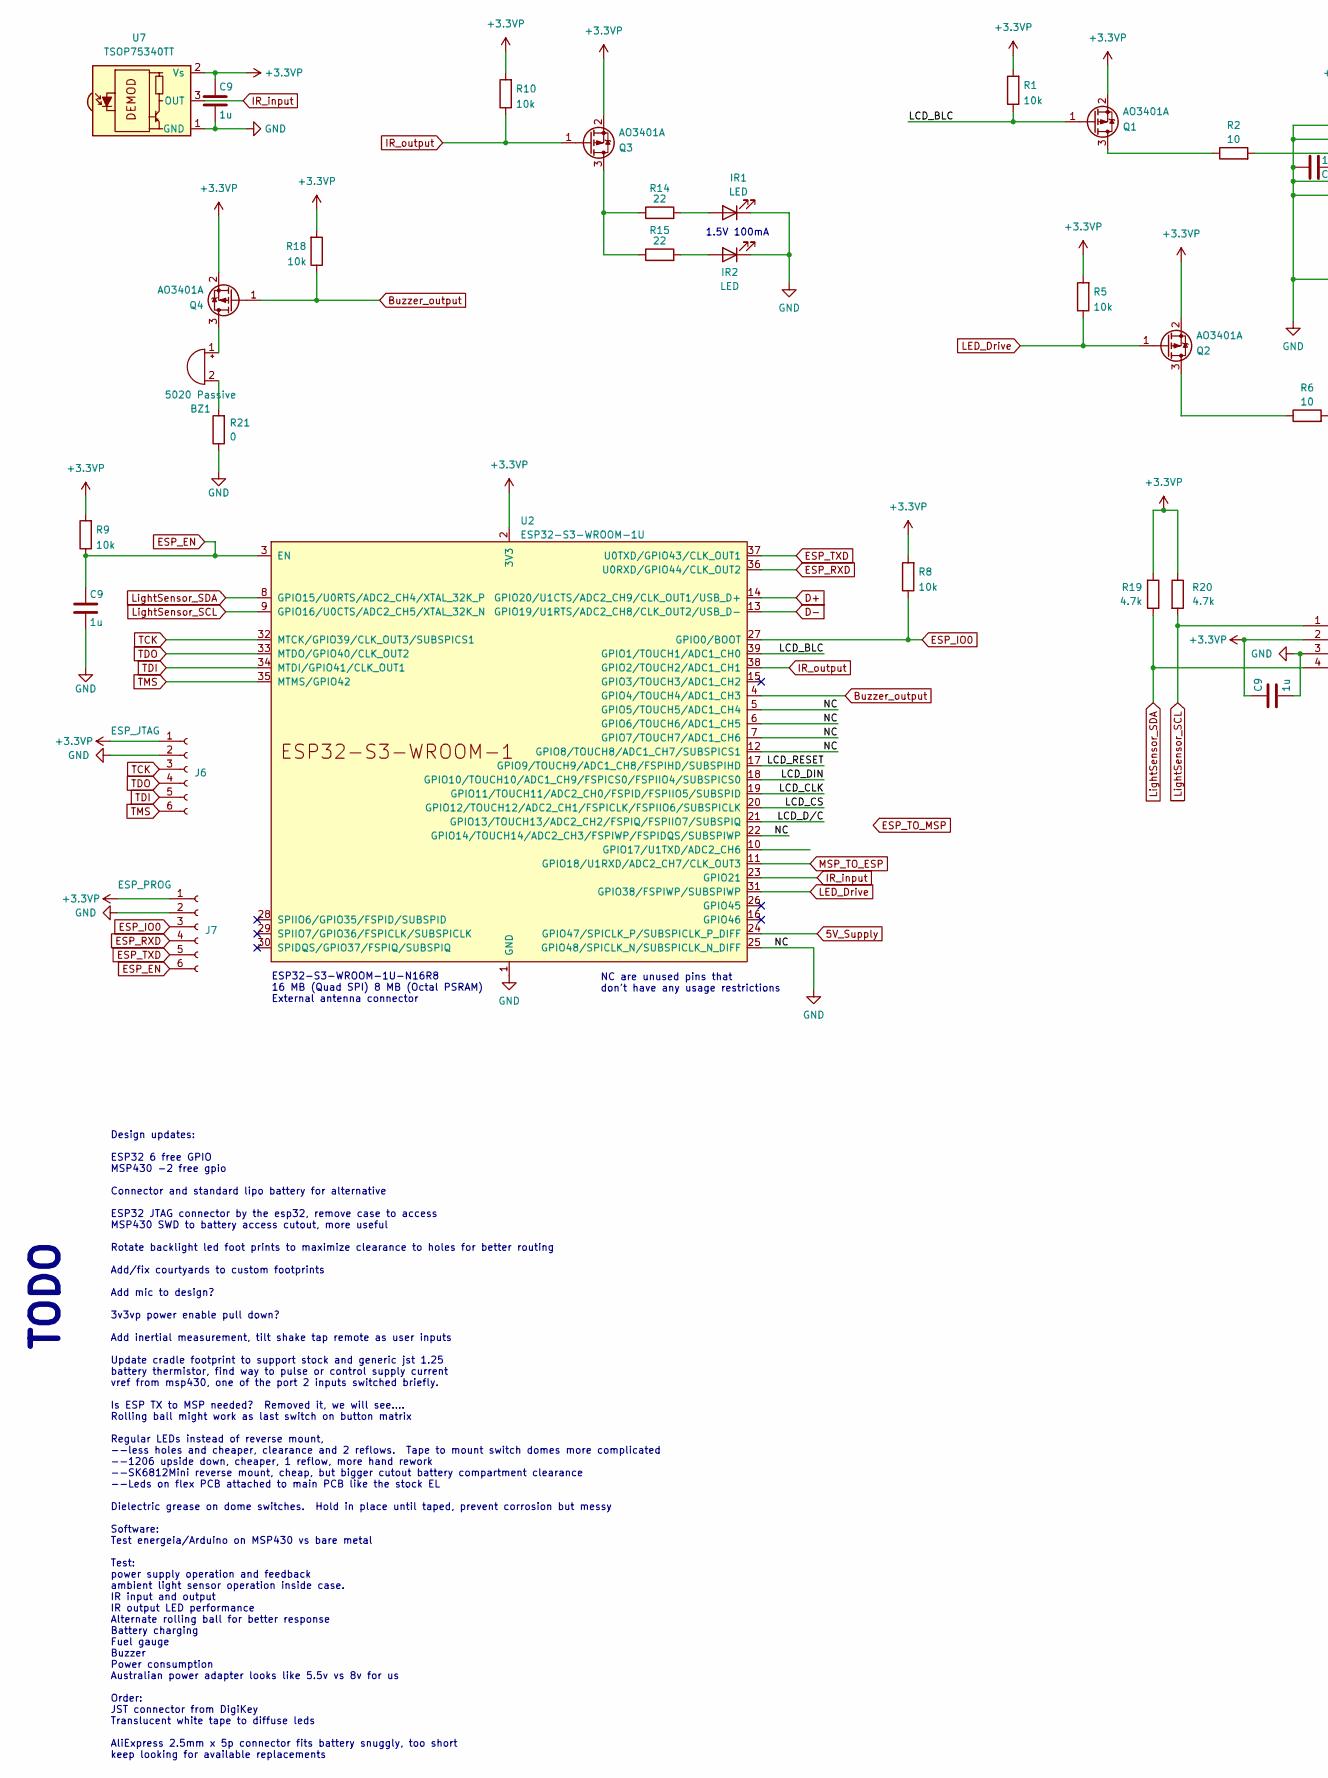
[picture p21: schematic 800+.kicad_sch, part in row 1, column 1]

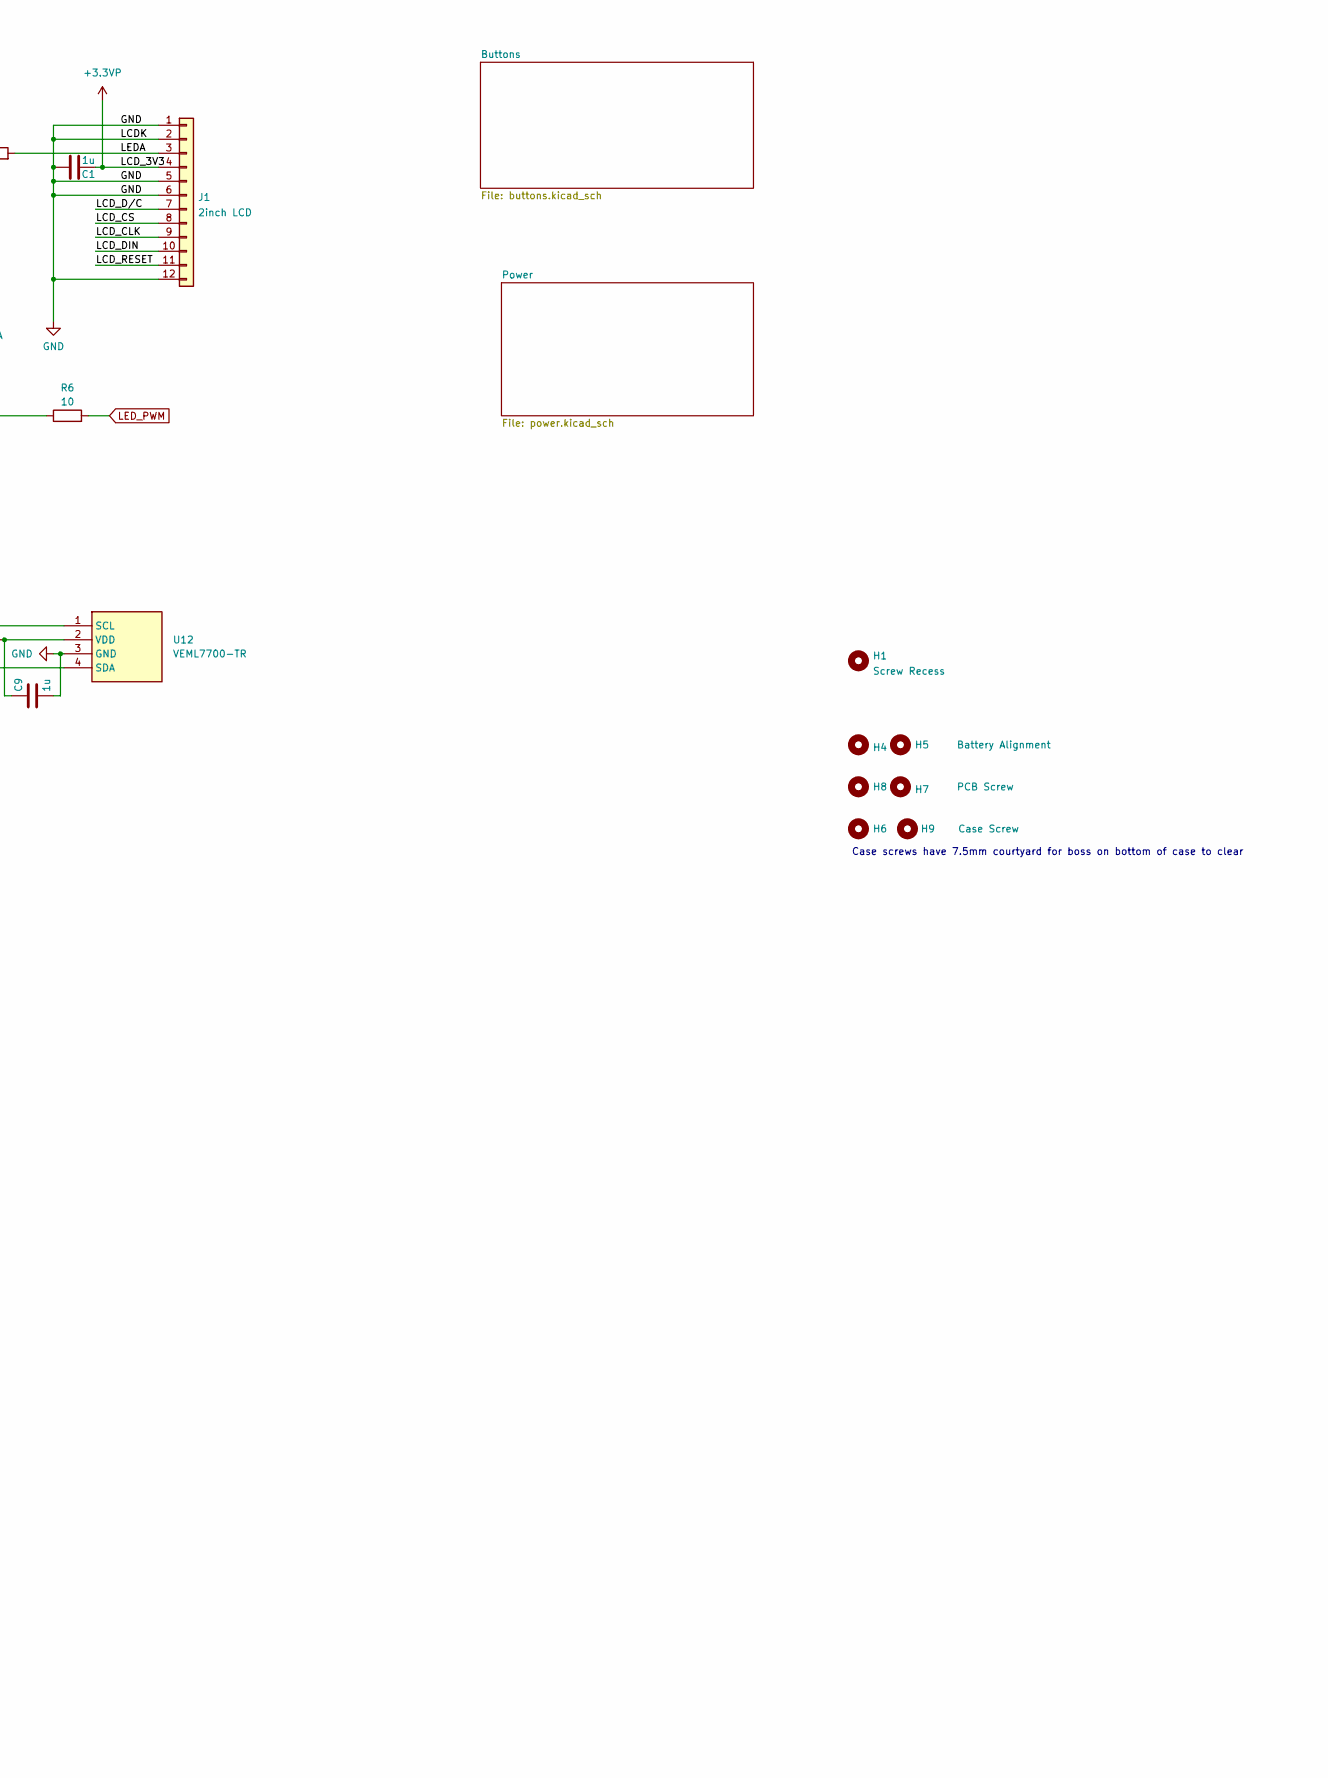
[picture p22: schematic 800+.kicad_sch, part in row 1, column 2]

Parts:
BZ1: 5020 Passive; 5020passiveBuzzer
C1, C9: 1u; C_0805_2012Metric
H1: Screw Recess; MountingHole_5mm
H4, H5: Battery Alignment; MountingHole_2.1mm
H6, H9: Case Screw; MountingHole_Boss
H7, H8: PCB Screw; MountingHole_2.2mm_M2
IR1, IR2: LED; IR_led
J1: 2inch LCD; 2inch_LCD
J6: ESP_JTAG; PinHeader_1x06_P2.54mm_Vertical
J7: ESP_PROG; PinHeader_1x06_P2.54mm_Vertical
Q1, Q2, Q3, Q4: AO3401A; SOT-23
R1, R5, R8, R9, R10, R18: 10k; R_0805_2012Metric
R2, R6: 10; R_1210_3225Metric
R14, R15: 22; R_1210_3225Metric
R19, R20: 4.7k; R_0805_2012Metric
R21: 0; R_1206_3216Metric
U2: ESP32-S3-WROOM-1U; ESP32-S3-WROOM-1
U7: TSOP75340TT; IR_input
U12: VEML7700-TR; VEML7700; Mouser Part Number 78-VEML7700-TT

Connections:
5V_Supply: U2.24 (GPIO47/SPICLK_P/SUBSPICLK_P_DIFF); also elsewhere on the board
/LCD_BLC: Q1.1 (G), R1.1, U2.39 (GPIO1/TOUCH1/ADC1_CH0)
/LCD_CLK: J1.9, U2.19 (GPIO11/TOUCH11/ADC2_CH0/FSPID/FSPIIO5/S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)
/LCD_CS: J1.8, U2.20 (GPIO12/TOUCH12/ADC2_CH1/FSPICLK/FSPIIO6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)
/LCD_DIN: J1.10, U2.18 (GPIO10/TOUCH10/ADC1_CH9/FSPICS0/FSPIIO4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)
/LCD_D/C: J1.7, U2.21 (GPIO13/TOUCH13/ADC2_CH2/FSPIQ/FSPIIO7/S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)
/LCD_RESET: J1.11, U2.17 (GPIO9/TOUCH9/ADC1_CH8/FSPIHD/SUBSPIHD)
/LEDA: J1.3, R2.2
Buzzer_output: Q4.1 (G), R18.1, U2.4 (GPIO4/TOUCH4/ADC1_CH3)
D+: U2.14 (GPIO20/U1CTS/ADC2_CH9/CLK_OUT1/USB_D+); also elsewhere on the board
D-: U2.13 (GPIO19/U1RTS/ADC2_CH8/CLK_OUT2/USB_D-); also elsewhere on the board
ESP_IO0: J7.3, R8.1, U2.27 (GPIO0/BOOT)
ESP_RXD: J7.4, U2.36 (U0RXD/GPIO44/CLK_OUT2)
ESP_TXD: J7.5, U2.37 (U0TXD/GPIO43/CLK_OUT1)
GND: C1.1, C9.2, IR1.1 (K), IR2.1 (K), J1.1, J1.2, J1.5, J1.6, J1.12, J6.2, J7.2, R21.1, U2.1 (GND), U2.5 (GPIO5/TOUCH5/ADC1_CH4), U2.6 (GPIO6/TOUCH6/ADC1_CH5), U2.7 (GPIO7/TOUCH7/ADC1_CH6), U2.12 (GPIO8/TOUCH8/ADC1_CH7/SUBSPICS1), U2.22 (GPIO14/TOUCH14/ADC2_CH3/FSPIWP/FSPIDQS/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), U2.25 (GPIO48/SPICLK_N/SUBSPICLK_N_DIFF), U2.40 (GND), U2.41 (GND), U7.1 (GND), U12.3 (GND); also elsewhere on the board
IR_input: U2.23 (GPIO21), U7.3 (OUT)
IR_output: Q3.1 (G), R10.1, U2.38 (GPIO2/TOUCH2/ADC1_CH1)
LED_Drive: Q2.1 (G), R5.1, U2.31 (GPIO38/FSPIWP/SUBSPIWP)
LED_PWM: R6.2; also elsewhere on the board
LightSensor_SCL: R20.2, U2.9 (GPIO16/U0CTS/ADC2_CH5/XTAL_32K_N), U12.1 (SCL)
LightSensor_SDA: R19.1, U2.8 (GPIO15/U0RTS/ADC2_CH4/XTAL_32K_P), U12.4 (SDA)
MSP_TO_ESP: U2.11 (GPIO18/U1RXD/ADC2_CH7/CLK_OUT3); also elsewhere on the board
unnamed: BZ1.1 (+), Q4.3 (D)
unnamed: BZ1.2 (-), R21.2
unnamed: IR1.2 (A), R14.2
unnamed: IR2.2 (A), R15.2
unnamed: Q1.3 (D), R2.1
unnamed: Q2.3 (D), R6.1
unnamed: Q3.3 (D), R14.1, R15.1
TCK: J6.3, U2.32 (MTCK/GPIO39/CLK_OUT3/SUBSPICS1)
TDI: J6.5, U2.34 (MTDI/GPIO41/CLK_OUT1)
TDO: J6.4, U2.33 (MTDO/GPIO40/CLK_OUT2)
TMS: J6.6, U2.35 (MTMS/GPIO42)

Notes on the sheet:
NC are unused pins that don't have any usage restrictions
TODO
Case screws have 7.5mm courtyard for boss on bottom of case to clear
1.5V 100mA
Design updates: ESP32 6 free GPIO MSP430 -2 free gpio Connector and standard lipo battery for alternative ESP32 JTAG connector by the esp32, remove case to access MSP430 SWD to battery access cutout, more useful Rotate backlight led foot prints to maximize clearance to holes for better routing Add/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
ESP32-S3-WROOM-1U-N16R8 16 MB (Quad SPI) 8 MB (Octal PSRAM) External antenna connector

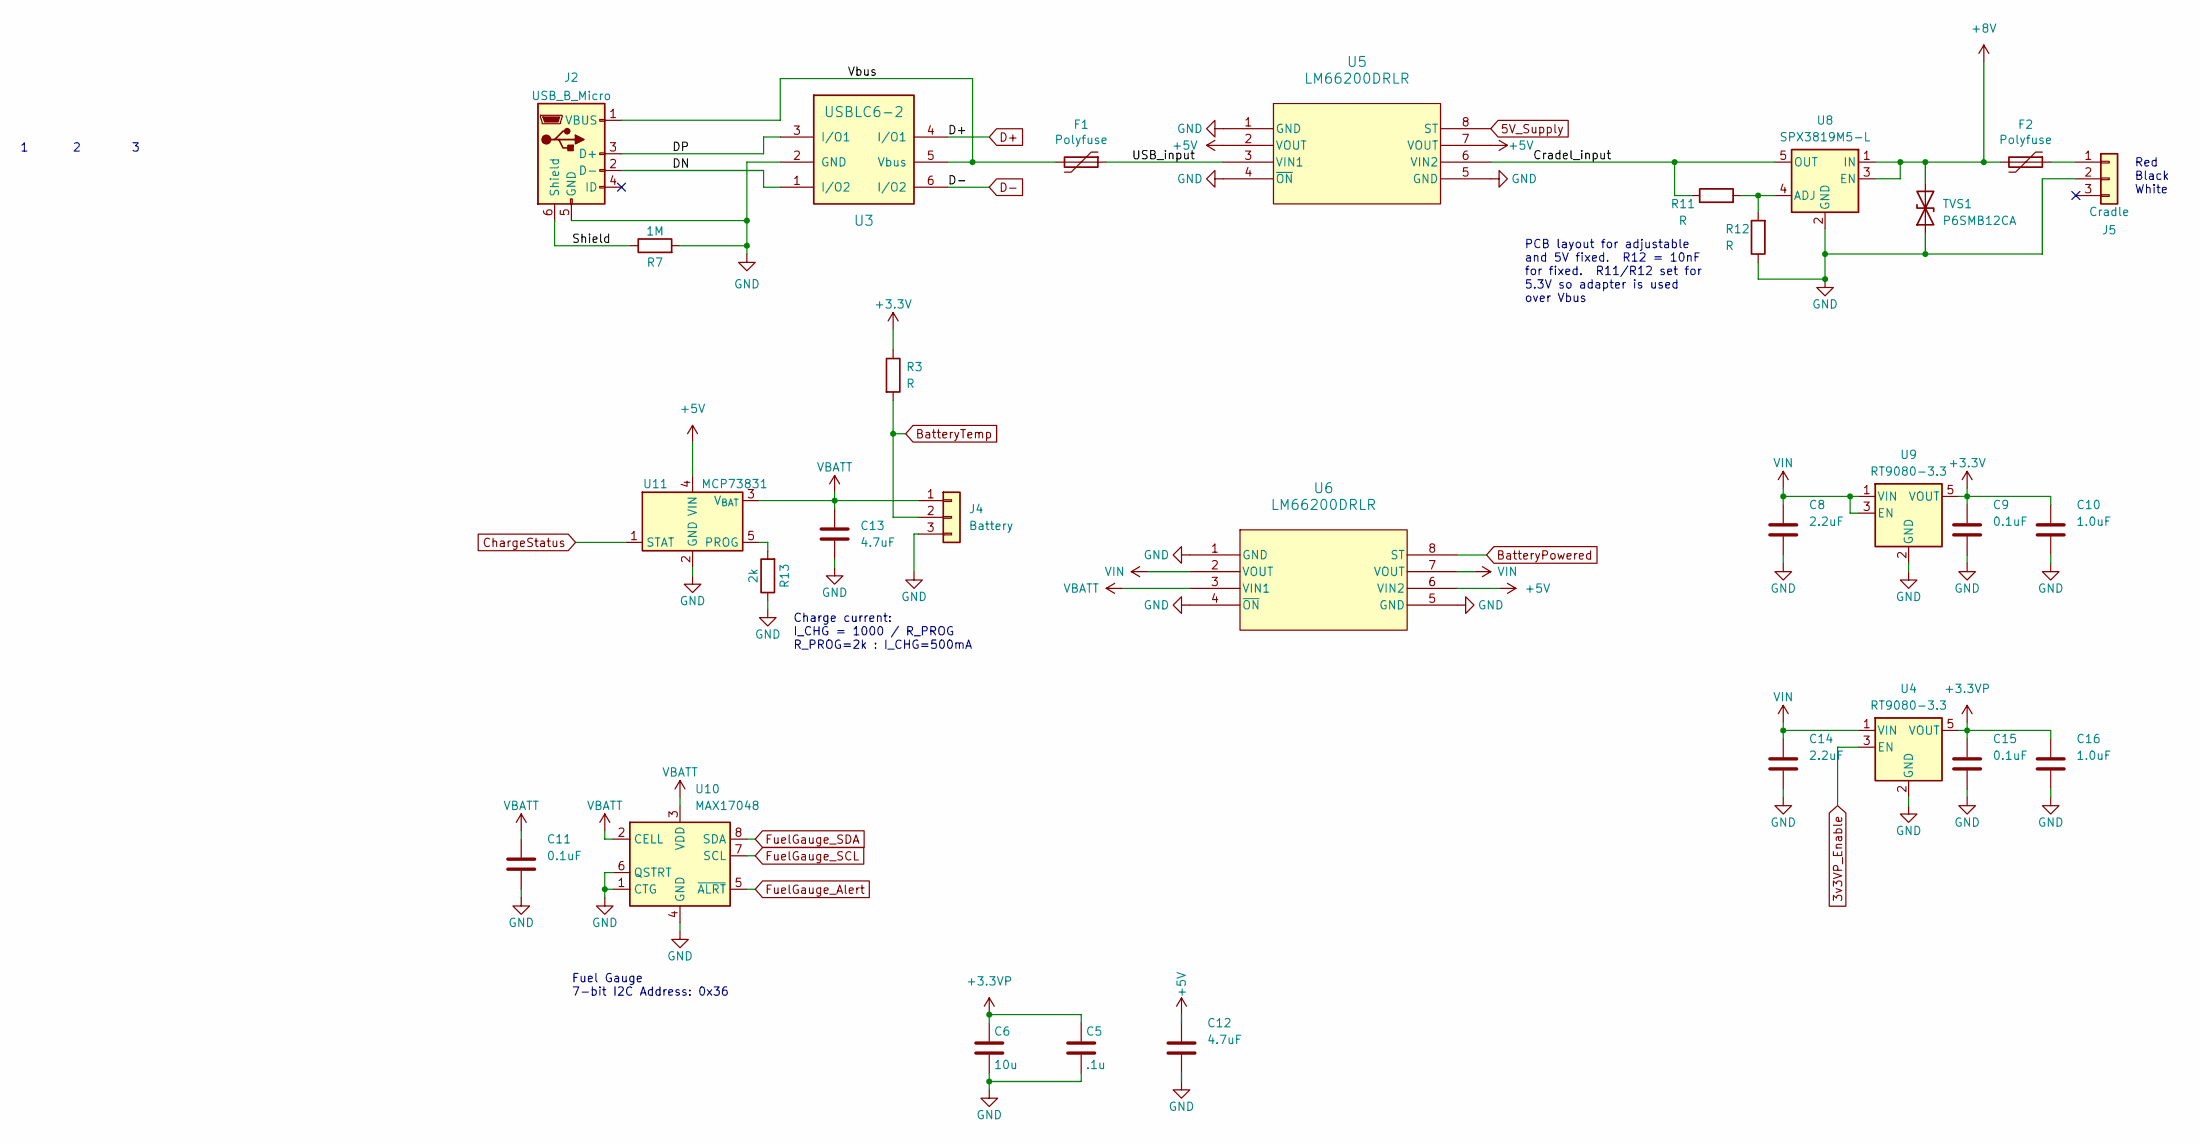
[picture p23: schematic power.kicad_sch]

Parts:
C5: .1u; C_0805_2012Metric
C6: 10u; C_0805_2012Metric
C8, C14: 2.2uF; C_0805_2012Metric
C9, C11, C15: 0.1uF; C_0805_2012Metric
C10, C16: 1.0uF; C_0805_2012Metric
C12, C13: 4.7uF; C_0805_2012Metric
F1, F2: Polyfuse; R_1210_3225Metric_Pad1.30x2.65mm_HandSolder
J2: USB_B_Micro; USB_Mini-B_Wuerth_65100516121_Horizontal
J4: Battery; Battery_reuse
J5: Cradle; JST_GH_BM03B-GHS-TBT_1x03-1MP_P1.25mm_Vertical
R3, R11, R12: R; R_0805_2012Metric
R7: 1M; R_0805_2012Metric
R13: 2k; R_0805_2012Metric
TVS1: P6SMB12CA; D_SMB
U3: USBLC6-2; SOT-23-6
U4, U9: RT9080-3.3; SOT-23-5
U5, U6: LM66200DRLR; SOT-583-8
U8: SPX3819M5-L; SOT-23-5
U10: MAX17048; TDFN-8-1EP_2x2mm_P0.5mm_EP0.8x1.4mm
U11: MCP73831; SOT-23-5

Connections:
3v3VP_Enable: U4.3 (EN); also elsewhere on the board
5V_Supply: U5.8 (ST); also elsewhere on the board
+5V: C12.1, U5.2 (VOUT), U5.7 (VOUT), U6.6 (VIN2), U11.4 (VIN)
+8V: F2.2, TVS1.2 (A2), U8.1 (IN), U8.3 (EN)
/Power/Cradel_input: R11.1, U5.6 (VIN2), U8.5 (OUT)
/Power/DN: J2.2 (D-), U3.1 (I/O2)
/Power/DP: J2.3 (D+), U3.3 (I/O1)
/Power/Shield: J2.6 (Shield), R7.1
/Power/USB_input: F1.1, U5.3 (VIN1)
/Power/Vbus: F1.2, J2.1 (VBUS), U3.5 (Vbus)
BatteryPowered: U6.8 (ST); also elsewhere on the board
BatteryTemp: J4.2, R3.2; also elsewhere on the board
ChargeStatus: U11.1 (STAT); also elsewhere on the board
D+: U3.4 (I/O1); also elsewhere on the board
D-: U3.6 (I/O2); also elsewhere on the board
FuelGauge_Alert: U10.5 (~ALRT); also elsewhere on the board
FuelGauge_SCL: U10.7 (SCL); also elsewhere on the board
FuelGauge_SDA: U10.8 (SDA); also elsewhere on the board
GND: C5.2, C6.2, C8.2, C9.2, C10.2, C11.2, C12.2, C13.2, C14.2, C15.2, C16.2, J2.5 (GND), J4.3, J5.2, R7.2, R12.1, R13.1, TVS1.1 (A1), U3.2 (GND), U4.2 (GND), U5.1 (GND), U5.4 (~ON), U5.5 (GND), U6.1 (GND), U6.4 (~ON), U6.5 (GND), U8.2 (GND), U9.2 (GND), U10.1 (CTG), U10.4 (GND), U10.6 (QSTRT), U10.9 (GND), U11.2 (GND); also elsewhere on the board
unnamed: F2.1, J5.1
unnamed: R11.2, R12.2, U8.4 (ADJ)
unnamed: R13.2, U11.5 (PROG)
VBATT: C11.1, C13.1, J4.1, U6.3 (VIN1), U10.2 (CELL), U10.3 (VDD), U11.3 (V_{BAT})
VIN: C8.1, C14.1, U4.1 (VIN), U6.2 (VOUT), U6.7 (VOUT), U9.1 (VIN), U9.3 (EN)

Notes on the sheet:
Fuel Gauge 7-bit I2C Address: 0x36
PCB layout for adjustable and 5V fixed. R12 = 10nF for fixed. R11/R12 set for 5.3V so adapter is used over Vbus
Red Black White
Charge current: I_CHG = 1000 / R_PROG R_PROG=2k : I_CHG=500mA
1 2 3

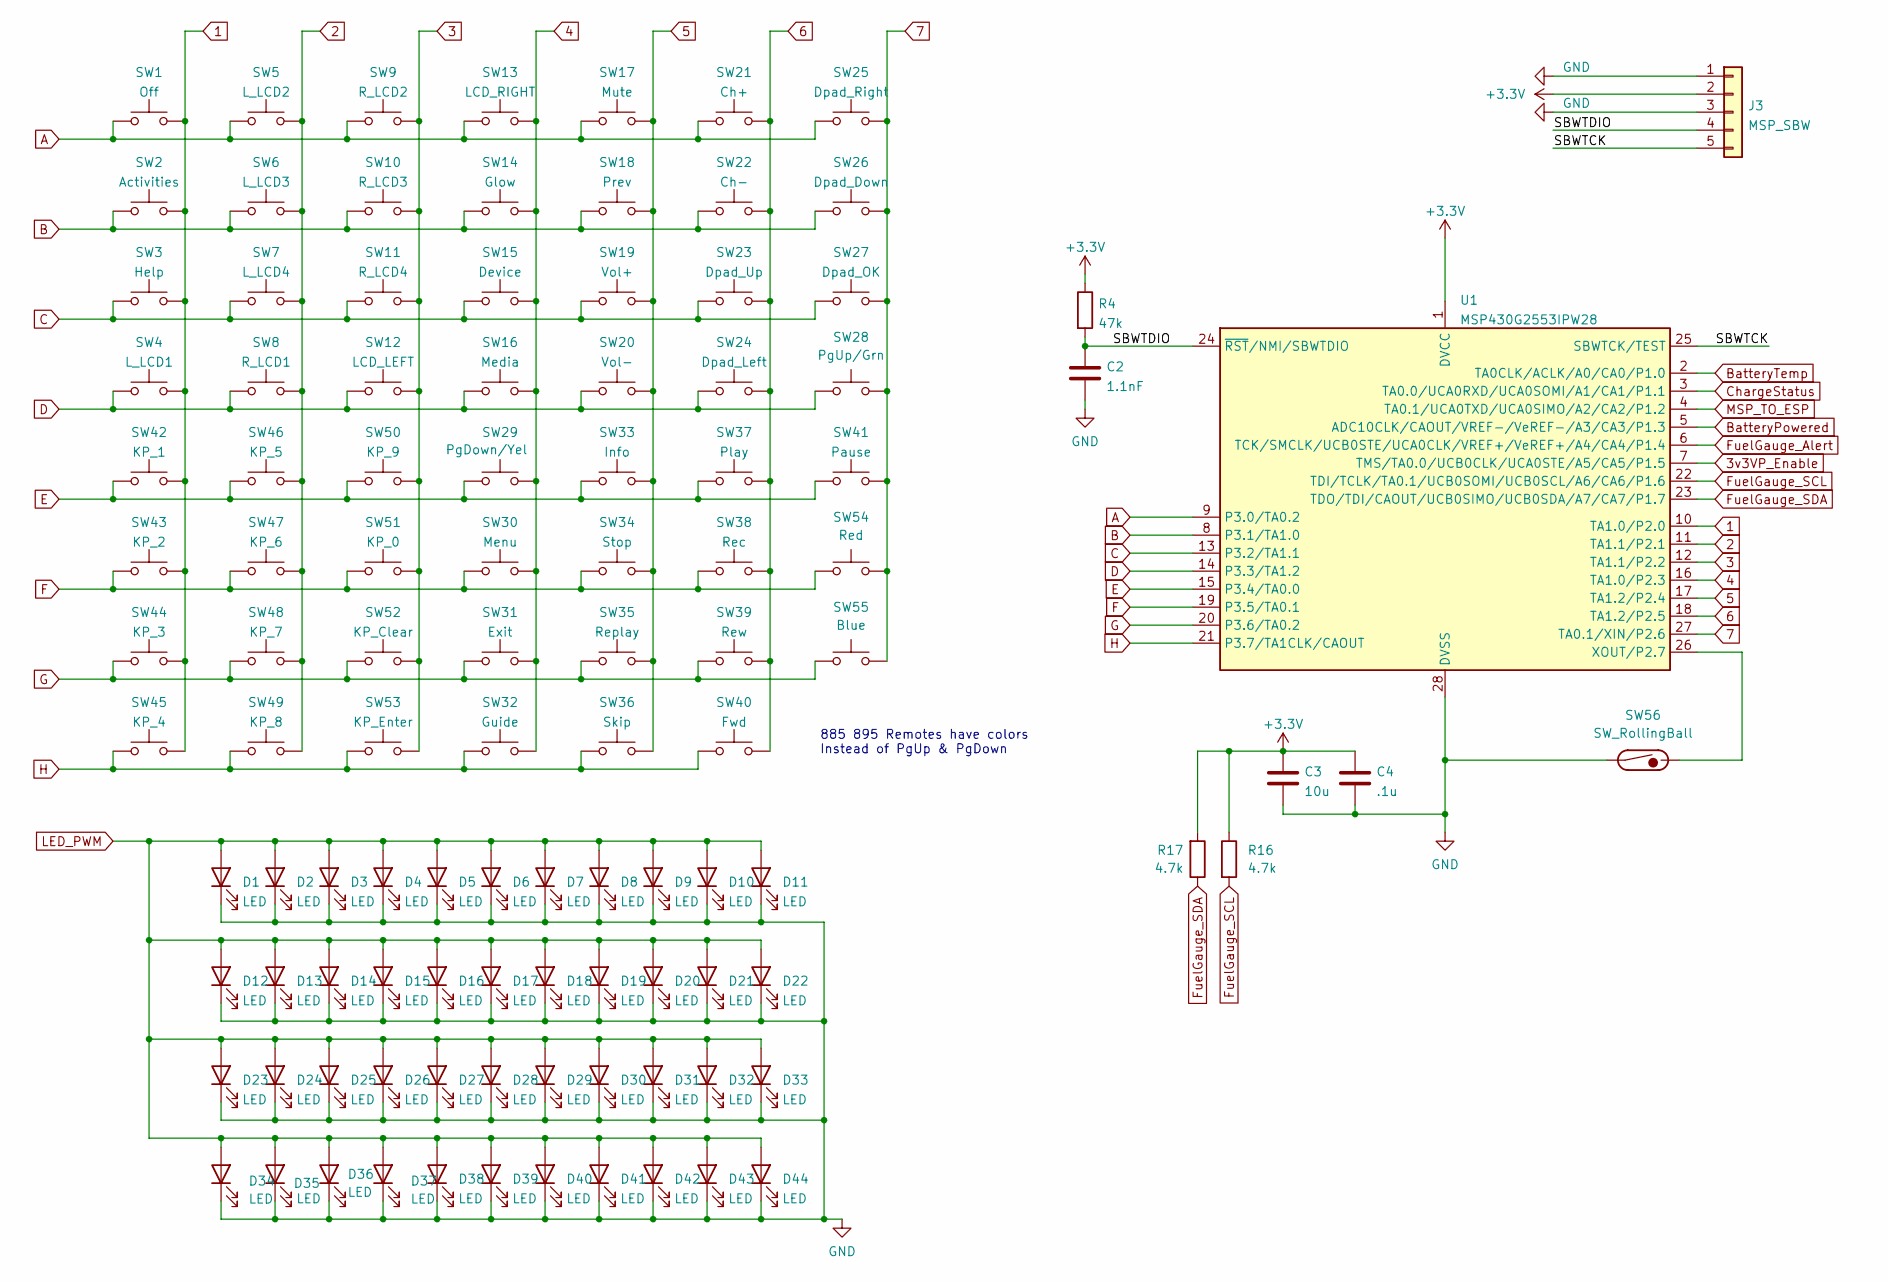
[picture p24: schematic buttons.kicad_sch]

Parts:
C2: 1.1nF; C_0805_2012Metric
C3: 10u; C_0805_2012Metric
C4: .1u; C_0805_2012Metric
D1, D2, D3, D4, D5, D6, D7, D8, D9, D10, D11, D12, D13, D14, D15, D16, D17, D18, D19, D20, D21, D22, D23, D24, D25, D26, D27, D28, D29, D30, D31, D32, D33, D34, D35, D36, D37, D38, D39, D40, D41, D42, D43, D44: LED; C265_reverse_mount_led_DRC
J3: MSP_SBW; PinHeader_1x05_P2.54mm_Vertical
R4: 47k; R_0805_2012Metric
R16, R17: 4.7k; R_0805_2012Metric
SW1: Off; 4mm Dome
SW2: Activities; 4mm Dome
SW3: Help; 4mm Dome
SW4: L_LCD1; 4mm Dome
SW5: L_LCD2; 4mm Dome
SW6: L_LCD3; 4mm Dome
SW7: L_LCD4; 4mm Dome
SW8: R_LCD1; 4mm Dome
SW9: R_LCD2; 4mm Dome
SW10: R_LCD3; 4mm Dome
SW11: R_LCD4; 4mm Dome
SW12: LCD_LEFT; 4mm Dome
SW13: LCD_RIGHT; 4mm Dome
SW14: Glow; 4mm Dome
SW15: Device; 4mm Dome
SW16: Media; 4mm Dome
SW17: Mute; 4mm Dome
SW18: Prev; 4mm Dome
SW19: Vol+; 4mm Dome
SW20: Vol-; 4mm Dome
SW21: Ch+; 4mm Dome
SW22: Ch-; 4mm Dome
SW23: Dpad_Up; 4mm Dome
SW24: Dpad_Left; 4mm Dome
SW25: Dpad_Right; 4mm Dome
SW26: Dpad_Down; 4mm Dome
SW27: Dpad_OK; 4mm Dome
SW28: PgUp/Grn; 4mm Dome
SW29: PgDown/Yel; 4mm Dome
SW30: Menu; 4mm Dome
SW31: Exit; 4mm Dome
SW32: Guide; 4mm Dome
SW33: Info; 4mm Dome
SW34: Stop; 4mm Dome
SW35: Replay; 4mm Dome
SW36: Skip; 4mm Dome
SW37: Play; 4mm Dome
SW38: Rec; 4mm Dome
SW39: Rew; 4mm Dome
SW40: Fwd; 4mm Dome
SW41: Pause; 4mm Dome
SW42: KP_1; 4mm Dome
SW43: KP_2; 4mm Dome
SW44: KP_3; 4mm Dome
SW45: KP_4; 4mm Dome
SW46: KP_5; 4mm Dome
SW47: KP_6; 4mm Dome
SW48: KP_7; 4mm Dome
SW49: KP_8; 4mm Dome
SW50: KP_9; 4mm Dome
SW51: KP_0; 4mm Dome
SW52: KP_Clear; 4mm Dome
SW53: KP_Enter; 4mm Dome
SW54: Red; 4mm Dome
SW55: Blue; 4mm Dome
SW56: SW_RollingBall; R_1210_3225Metric
U1: MSP430G2553IPW28; TSSOP-28_4.4x9.7mm_P0.65mm

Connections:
1: SW1.2, SW2.2, SW3.2, SW4.2, SW42.2, SW43.2, SW44.2, SW45.2, U1.10 (TA1.0/P2.0)
2: SW5.2, SW6.2, SW7.2, SW8.2, SW46.2, SW47.2, SW48.2, SW49.2, U1.11 (TA1.1/P2.1)
3: SW9.2, SW10.2, SW11.2, SW12.2, SW50.2, SW51.2, SW52.2, SW53.2, U1.12 (TA1.1/P2.2)
3v3VP_Enable: U1.7 (TMS/TA0.0/UCB0CLK/UCA0STE/A5/CA5/P1.5); also elsewhere on the board
4: SW13.2, SW14.2, SW15.2, SW16.2, SW29.2, SW30.2, SW31.2, SW32.2, U1.16 (TA1.0/P2.3)
5: SW17.2, SW18.2, SW19.2, SW20.2, SW33.2, SW34.2, SW35.2, SW36.2, U1.17 (TA1.2/P2.4)
6: SW21.2, SW22.2, SW23.2, SW24.2, SW37.2, SW38.2, SW39.2, SW40.2, U1.18 (TA1.2/P2.5)
7: SW25.2, SW26.2, SW27.2, SW28.2, SW41.2, SW54.2, SW55.2, U1.27 (TA0.1/XIN/P2.6)
/Buttons/SBWTCK: J3.5, U1.25 (SBWTCK/TEST)
/Buttons/SBWTDIO: C2.1, J3.4, R4.2, U1.24 (~RST/NMI/SBWTDIO)
A: SW1.1, SW5.1, SW9.1, SW13.1, SW17.1, SW21.1, SW25.1, U1.9 (P3.0/TA0.2)
B: SW2.1, SW6.1, SW10.1, SW14.1, SW18.1, SW22.1, SW26.1, U1.8 (P3.1/TA1.0)
BatteryPowered: U1.5 (ADC10CLK/CAOUT/VREF-/VeREF-/A3/CA3/P1.3); also elsewhere on the board
BatteryTemp: U1.2 (TA0CLK/ACLK/A0/CA0/P1.0); also elsewhere on the board
C: SW3.1, SW7.1, SW11.1, SW15.1, SW19.1, SW23.1, SW27.1, U1.13 (P3.2/TA1.1)
ChargeStatus: U1.3 (TA0.0/UCA0RXD/UCA0SOMI/A1/CA1/P1.1); also elsewhere on the board
D: SW4.1, SW8.1, SW12.1, SW16.1, SW20.1, SW24.1, SW28.1, U1.14 (P3.3/TA1.2)
E: SW29.1, SW33.1, SW37.1, SW41.1, SW42.1, SW46.1, SW50.1, U1.15 (P3.4/TA0.0)
F: SW30.1, SW34.1, SW38.1, SW43.1, SW47.1, SW51.1, SW54.1, U1.19 (P3.5/TA0.1)
FuelGauge_Alert: U1.6 (TCK/SMCLK/UCB0STE/UCA0CLK/VREF+/VeREF+/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); also elsewhere on the board
FuelGauge_SCL: R16.2, U1.22 (TDI/TCLK/TA0.1/UCB0SOMI/UCB0SCL/A6/CA6/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); also elsewhere on the board
FuelGauge_SDA: R17.1, U1.23 (TDO/TDI/CAOUT/UCB0SIMO/UCB0SDA/A7/CA7/P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); also elsewhere on the board
G: SW31.1, SW35.1, SW39.1, SW44.1, SW48.1, SW52.1, SW55.1, U1.20 (P3.6/TA0.2)
GND: C2.2, C3.2, C4.2, D1.1 (K), D2.1 (K), D3.1 (K), D4.1 (K), D5.1 (K), D6.1 (K), D7.1 (K), D8.1 (K), D9.1 (K), D10.1 (K), D11.1 (K), D12.1 (K), D13.1 (K), D14.1 (K), D15.1 (K), D16.1 (K), D17.1 (K), D18.1 (K), D19.1 (K), D20.1 (K), D21.1 (K), D22.1 (K), D23.1 (K), D24.1 (K), D25.1 (K), D26.1 (K), D27.1 (K), D28.1 (K), D29.1 (K), D30.1 (K), D31.1 (K), D32.1 (K), D33.1 (K), D34.1 (K), D35.1 (K), D36.1 (K), D37.1 (K), D38.1 (K), D39.1 (K), D40.1 (K), D41.1 (K), D42.1 (K), D43.1 (K), D44.1 (K), J3.1, J3.3, SW56.1, U1.28 (DVSS); also elsewhere on the board
H: SW32.1, SW36.1, SW40.1, SW45.1, SW49.1, SW53.1, U1.21 (P3.7/TA1CLK/CAOUT)
LED_PWM: D1.2 (A), D2.2 (A), D3.2 (A), D4.2 (A), D5.2 (A), D6.2 (A), D7.2 (A), D8.2 (A), D9.2 (A), D10.2 (A), D11.2 (A), D12.2 (A), D13.2 (A), D14.2 (A), D15.2 (A), D16.2 (A), D17.2 (A), D18.2 (A), D19.2 (A), D20.2 (A), D21.2 (A), D22.2 (A), D23.2 (A), D24.2 (A), D25.2 (A), D26.2 (A), D27.2 (A), D28.2 (A), D29.2 (A), D30.2 (A), D31.2 (A), D32.2 (A), D33.2 (A), D34.2 (A), D35.2 (A), D36.2 (A), D37.2 (A), D38.2 (A), D39.2 (A), D40.2 (A), D41.2 (A), D42.2 (A), D43.2 (A), D44.2 (A); also elsewhere on the board
MSP_TO_ESP: U1.4 (TA0.1/UCA0TXD/UCA0SIMO/A2/CA2/P1.2); also elsewhere on the board
unnamed: SW56.2, U1.26 (XOUT/P2.7)

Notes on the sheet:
885 895 Remotes have colors Instead of PgUp & PgDown

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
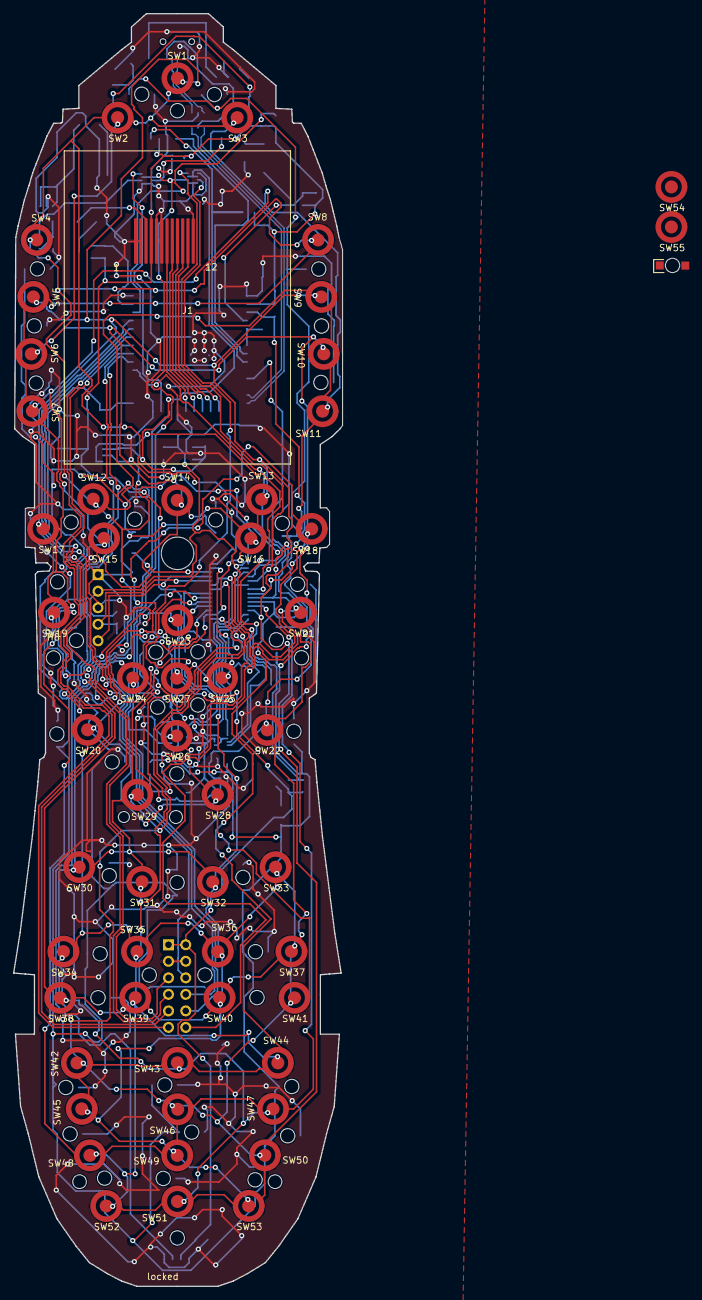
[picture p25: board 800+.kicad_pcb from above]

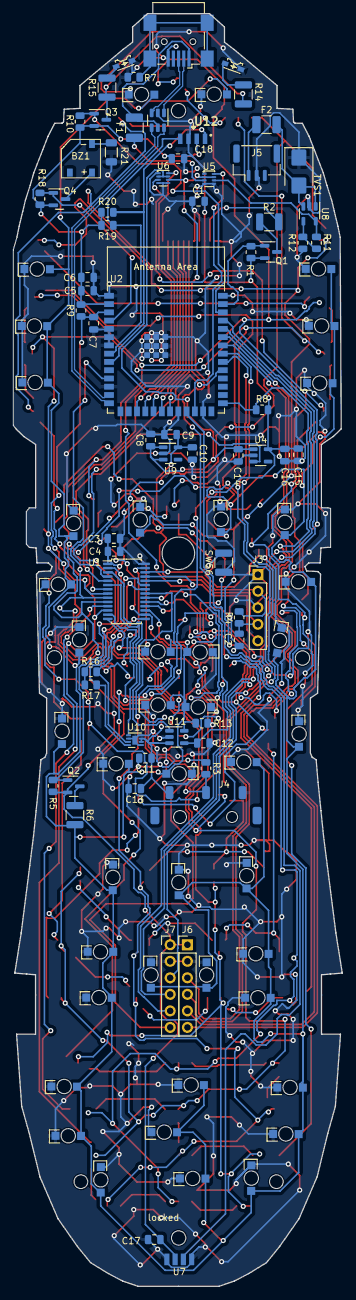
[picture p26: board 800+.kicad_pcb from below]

Board: 2 copper layers, 50.5 x 195.6 mm, 175 parts (111 on the bottom side), 74 nets.

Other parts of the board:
C7, C17, C18: 1u; C_0805_2012Metric

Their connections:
GND: C7.2, C17.2, C18.2; also elsewhere on the board

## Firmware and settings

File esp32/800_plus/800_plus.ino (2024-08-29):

//ESP32 board package 3.0.3
//ESP32-S3-WROOM-1-N16R8 16 MB (Quad SPI) 8 MB (Octal SPI)
//FQBN: esp32:esp32:esp32s3:CDCOnBoot=cdc,FlashSize=16M,PSRAM=opi

//2.5.43
#include <TFT_eSPI.h>

//LVGL 9.2
#include <lvgl.h>

// #include "WiFi.h"

//About 7 pixels obscured at top and 20 at bottom
#include "ui.h"

#define LCD_BL_GPIO          1       //LOW is ON
#define BUTTON_LED_GPIO      38      //LOW is ON

#define IR_RECEIVE_PIN          21 
#define IR_SEND_PIN              2  
#define NO_LED_FEEDBACK_CODE
// #define USE_OPEN_DRAIN_OUTPUT_FOR_SEND_PIN
// Need greater than 4.4 for ESP32 3.X board suppport
#include <IRremote.hpp> // include the library

#define BUZZER_PIN          4 
// const char * arkanoid = "Arkanoid:d=4,o=5,b=140:8g6,16p,16g.6,2a#6,32p,8a6,8g6,8f6,8a6,2g6";
// #include <NonBlockingRtttl.h>
//#include <PlayRtttl.hpp>

char StarWarsInRam[] =
        "StarWars:d=32,o=5,b=45,l=2,s=N:p,f#,f#,f#,8b.,8f#.6,e6,d#6,c#6,8b.6,16f#.6,e6,d#6,c#6,8b.6,16f#.6,e6,d#6,e6,8c#6";

#define i2c_SDA 15
#define i2c_SCL 16
#include <Wire.h>

#include <SparkFun_VEML7700_Arduino_Library.h>
VEML7700 lightSensor; 

#define INPUT_5V_SUPPLY 47  //High for USB, LOW for Cradle

#define USB_Serial Serial
#define MSP_Serial Serial1

#define SCREEN_WIDTH TFT_WIDTH
#define SCREEN_HEIGHT TFT_HEIGHT
#define DRAW_BUF_SIZE (SCREEN_WIDTH * SCREEN_HEIGHT / 10 * (LV_COLOR_DEPTH / 8))
uint32_t draw_buf[DRAW_BUF_SIZE / 4];

char button_value[10];

// LVGL logging is enabled, it will inform the user about what is happening in the library
void log_print(lv_log_level_t level, const char * buf) {
  LV_UNUSED(level);
  USB_Serial.println(buf);
  USB_Serial.flush();
}

/*use Arduinos millis() as tick source*/
static uint32_t my_tick(void)
{
    return millis();
}

const char *get_var_lv_btn_press(){
  return button_value;
}

void set_var_lv_btn_press(const char *value){
  //ignore lvgl set request
}

void setup() {

  pinMode(LCD_BL_GPIO,OUTPUT);
  pinMode(BUTTON_LED_GPIO,OUTPUT);
  pinMode(IR_SEND_PIN,OUTPUT);
  
  digitalWrite(LCD_BL_GPIO,HIGH);
  digitalWrite(BUTTON_LED_GPIO,HIGH);  
  digitalWrite(IR_SEND_PIN,HIGH);  

  pinMode(INPUT_5V_SUPPLY,INPUT);

  //bool begin(int sdaPin, int sclPin, uint32_t frequency)
  Wire.begin(i2c_SDA, i2c_SCL,400000);


  // pinMode(BUZZER_PIN, OUTPUT);
  // digitalWrite(BUZZER_PIN,HIGH);

  // tone(BUZZER_PIN, 700, 1000);


  if (lightSensor.begin() == false)
  {
    Serial.println("Unable to communicate with the VEML7700. Please check the wiring. Freezing...");
    while (1)
      ;
  }  

  lightSensor.setSensitivityMode(VEML7700_SENSITIVITY_x2);


  //blocks on 2.0.14 code,okay in 3.0.2 & 2.0.17
  USB_Serial.begin(115200);
  
  MSP_Serial.begin(115200, SERIAL_8N1, 18, 17);

  USB_Serial.println("Serial started....");



  // Start the receiver and if not 3. parameter specified, take LED_BUILTIN pin from the internal boards definition as default feedback LED
  IrReceiver.begin(IR_RECEIVE_PIN, 0);  
  // IrSender.begin();
  
  USB_Serial.println("IrReceiver started....");

  lv_init();
  lv_log_register_print_cb(log_print);
  lv_tick_set_cb(my_tick);

  USB_Serial.println("lvgl started....");


  // Create a display object
  lv_display_t * disp;
  // Initialize the TFT display using the TFT_eSPI library
  disp = lv_tft_espi_create(SCREEN_WIDTH, SCREEN_HEIGHT, draw_buf, sizeof(draw_buf));
  lv_display_set_rotation(disp, LV_DISPLAY_ROTATION_180);

  //Check vertical and horizontal resolution of what lvgl sees
  lv_coord_t hor_res = lv_disp_get_hor_res(NULL);
  USB_Serial.print("LVGL Horizontal Resolution: ");
  USB_Serial.println(hor_res);
  
  //Check vertical and horizontal resolution of what lvgl sees
  lv_coord_t ver_res = lv_disp_get_ver_res(NULL);
  USB_Serial.print("LVGL Vertical Resolution: ");
  USB_Serial.println(ver_res);

  lv_coord_t disp_dpi = lv_disp_get_dpi(NULL);
  USB_Serial.print("LVGL Display DPI: ");
  USB_Serial.println(disp_dpi);

  ui_init();

  USB_Serial.println("ui_init started....");

  if(digitalRead(INPUT_5V_SUPPLY)==HIGH)
    USB_Serial.println("5V from USB");
  else
    USB_Serial.println("5V from USB");

  // ESP board 3.x
  ledcAttach(LCD_BL_GPIO, 12000, 8);
  ledcAttach(BUTTON_LED_GPIO, 12000, 8);

  // ESP board 2.X
  // ledcAttachPin(LCD_BL_GPIO, 1); // assign RGB led pins to channels
  // ledcAttachPin(BUTTON_LED_GPIO, 2);
  // ledcSetup(1, 12000, 8); // 12 kHz PWM, 8-bit resolution
  // ledcSetup(2, 12000, 8);

  //0 full, 255 off
  ledcWrite(1, 128);
  ledcWrite(2, 128);

}

int button=0;

void loop() {
  
  if(digitalRead(7)==HIGH) {
    digitalWrite(LCD_BL_GPIO,LOW);
    digitalWrite(BUTTON_LED_GPIO,LOW);
  } else{
    digitalWrite(LCD_BL_GPIO,LOW);
    digitalWrite(BUTTON_LED_GPIO,LOW);
  }

  while(MSP_Serial.available()) {
    button = MSP_Serial.read();
    if (button != 255) {
      USB_Serial.printf("millis %d:\tbutton: %d\n", millis(), button);
     }
  }

  if(button>0 && button < 0xFE) {
    sprintf(button_value, "%d", button);
    // USB_Serial.println(button_value);
    tick_screen_main();
    //IrSender.sendNEC(0x0101, button, 0);
    if(button==19) 
      IrSender.sendKaseikyo_Denon(0x014, 0x09, 5);
    if(button==20)
      IrSender.sendKaseikyo_Denon(0x114, 0x17, 5);
    // tone(BUZZER_PIN, 700, 1000);
    Serial.printf("Lux: %.2f\n",lightSensor.getLux()); 
  }
  else {
    sprintf(button_value, "880+");
    // USB_Serial.println(button_value);
    tick_screen_main();
    // noTone(BUZZER_PIN);
    // digitalWrite(BUZZER_PIN,HIGH);
  }
  //USB_Serial.printf("loop %d:\t%d\n", millis(), button);

    if (IrReceiver.decode()) {
      USB_Serial.println("IR decode:");
        /*
         * Print a summary of received data
         */
        if (IrReceiver.decodedIRData.protocol == UNKNOWN) {
            Serial.println(F("Received noise or an unknown (or not yet enabled) protocol"));
            // We have an unknown protocol here, print extended info
            IrReceiver.printIRResultRawFormatted(&Serial, true);
            IrReceiver.resume(); // Do it here, to preserve raw data for printing with printIRResultRawFormatted()
        } else {
            IrReceiver.resume(); // Early enable receiving of the next IR frame
            IrReceiver.printIRResultShort(&Serial);
            IrReceiver.printIRSendUsage(&Serial);
        }
        Serial.println();

        /*
         * Finally, check the received data and perform actions according to the received command
         */
        if (IrReceiver.decodedIRData.command == 0x10) {
            // do something
        } else if (IrReceiver.decodedIRData.command == 0x11) {
            // do something else
        }
    }

  lv_task_handler();  // let the GUI do its work
  delay(2);     
}

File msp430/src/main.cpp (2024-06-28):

#ifndef EXTERN 
#define EXTERN 
#endif

#include <Arduino.h>
#include <Wire.h>  //comment out line in twi_disable for 'UCBzCTLW0' undeclared error


#include "main.h"
#include "buttons.h"
#include "setup.h"


//P1.0 ESP Enable
//P1.6 ESP to GPIO7 HIGH Backlight on


#pragma vector = PORT2_VECTOR
__interrupt void PORT2_ISR_HOOK(void) {
  //Disable interrupt and configure for matrix scanning when button press detected
  P2IFG = 0;
  P3OUT = BIT0;
  P2IE = 0;
  last_button_scan=0;
  last_button_press=millis();
}

#pragma vector = TIMER0_A0_VECTOR
__interrupt void TIMER0_A0_ISR_HOOK(void) {
  // CCIFG is reset automatically;
  __bic_SR_register_on_exit(LPM0_bits);
}




void setup()
{
  Serial.println("Setup()");
  mcu_init();

  pinMode(P1_1, INPUT_PULLUP);  //Fuelgauge alert
  pinMode(P1_3, INPUT_PULLUP);  //Battery Powered
  pinMode(P1_4, INPUT_PULLDOWN);  //ChargeStatus
  pinMode(P1_5, OUTPUT);  //3v3VP Enable

  Serial.begin(115200);
  Wire.begin();
	
	last_button_scan=0;
	last_button_press = 0;
  
  // turn the LED on (HIGH is the voltage level)
  digitalWrite(P1_5, HIGH);

  Serial.println("loop");
  
  //Start timer in up mode for 1ms wakeups
  TA0CTL |= MC_1;  
 
}

void loop()
{

	if(millis()-last_button_scan > 5) {
    last_button_scan = millis();
    process_buttons();
	}

	if(millis()-last_button_press > 75 ) {
		Serial.write(0xFF);
	}

	if(millis()-last_button_press > 5000) {
    //Stop active scanning after last press
    //Setup port 2 interrupt with all rows HIGH
		P3OUT = 0xFE;
    P2IFG = 0;
		P2IE = 0xFF;
	}

  __bis_SR_register(LPM0_bits);
  
}

/*
__bic_SR_register_on_exit(LPM0_bits);
__bis_SR_register(LPM0_bits);
__no_operation();
__bis_SR_register(LPM0_bits | GIE);
__enable_interrupt();
__disable_interrupt(); */

/*


*/

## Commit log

2023-03-14 alpha pcb
    [800+-B_Cu.gbr, 800+-B_Mask.gbr, 800+-B_Paste.gbr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]
2023-03-14 msp430 test code
    [BCSplus_init.obj, CSL_init.obj, GPIO_init.obj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]
2024-05-07 alpha2 pcb
    [800+-B_Cu.gbr, 800+-B_Mask.gbr, 800+-B_Paste.gbr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]
2024-05-23 add blink demo for alpha2 esp32
2024-05-23 buttons working from msp to esp
2024-05-23 msp430 from ccs to platformio
    [BCSplus_init.obj, CSL_init.obj, GPIO_init.obj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]
2024-05-29 msp430 structure
    button logic changed to look up tables. 200 bytes less flash than the switch statements and faster
2024-05-31 esp & msp code
    add shock sensor to P2.7
2024-06-01 current working kikad
    [800+.kicad_pcb, 800+.kicad_sch, buttons.kicad_sch]
2024-06-06 add power to schematic
    [800+.kicad_sch, buttons.kicad_sch, power.kicad_sch]
2024-06-07 more schematic updates
    [800+.kicad_sch, buttons.kicad_sch, power.kicad_sch]
2024-06-07 ready to route????
    [800+.kicad_sch, buttons.kicad_sch]
2024-06-10 fix battery connector
    [800+.kicad_sch, power.kicad_sch]
2024-06-11 cradle connector
    [800+.kicad_sch, power.kicad_sch]
2024-06-13 parts placed
    [800+.kicad_pcb, 800+.kicad_sch, buttons.kicad_sch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]
2024-06-14 alpha3 pcb
    [800+-B_Mask.gbr, 800+-B_Silkscreen.gbr, 800+-Edge_Cuts.gbr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]
2024-06-14 fix VEML7700 direction
    [800+-B_Cu.gbr, 800+-B_Mask.gbr, 800+-B_Silkscreen.gbr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]
2024-06-20 readme updates
    [800+-B_Cu.gbr, 800+-B_Paste.gbr, 800+-B_Silkscreen.gbr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]
2024-06-23 prep for alpha3 pcb
2024-06-23 update todo and reference info
    [800+.kicad_sch, buttons.kicad_sch, power.kicad_sch]
2024-06-24 update case screws
    bottom courtyard added for case screws to account for boss on the case
    [800+.kicad_pcb, 800+.kicad_sch]
2024-06-26 msp edits
    [800+.csv]
2024-06-28 mounting boss
    [800+.kicad_sch]
2024-06-29 fix for serial.begin() blocking and tft.init() panic
    esp 3.0.2
    and tft_espi 2.5.43
    [800_plus.ino]
2024-06-29 ESP32 IR Recv
    Back to esp 2.0.17 for IRremote lib
2024-06-29 IR led fix
    [800+.kicad_sch]
2024-06-30 lux and buzzer
    [800+.kicad_sch]
2024-06-30 more esp code
    [800+.kicad_sch]
2024-08-29 library updates
    LVGL 9.2 is released
    Everything working with ESP board 3.0.3
    tft configuration in sketch folder
